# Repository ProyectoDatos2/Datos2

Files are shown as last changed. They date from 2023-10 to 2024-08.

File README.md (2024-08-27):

To change language:&nbsp;&nbsp;


# Datos² y EME

El proyecto [Datos²](https://datos2.redesclimaticas.com/) es una iniciativa de [OMIXOM](https://www.omixom.com/) En el se desarrolló un dispositivo Open-Source con el fin de recolectar, almacenar y compartir datos ambientales de la mano de proyectos de ciencia ciudadana y de la comunidad en general

Para contribuir al desarrollo de dispositivos que tomen datos, OMIXOM ha diseñado [EME](/Manual%20de%20uso.pdf) (Estación Meteorológica de uso Educativo), una estación meteorológica de bajo costo y fácil ensamblaje, ideal para proyectos educativos de tecnología y medio ambiente. EME está equipada con un sistema de sensores, telemetría y autonomía que permite medir variables como lluvia, temperatura, humedad y radiación UV, subiendo estos datos a la plataforma de Datos² sin necesidad de una red eléctrica.

<br><p align="center">
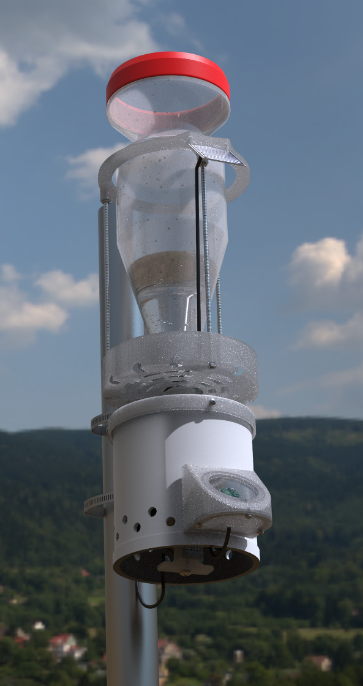
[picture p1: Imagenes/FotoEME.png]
  </p><br>

## Componentes y materiales
**Configuración de Impresión:**
- Altura de Capa: 0,2 mm
- Relleno: 30% al 50%
- Líneas de pared: 3
- Capas de Superficie: 3

<table align="center"><thead><tr>
      <th>Impresión 3D</th>
      <th>Cantidad</th></tr></thead><tbody><tr>
      <td align="center"><a href = "Impresion 3D STL\Pluviómetro\Pluv_Aro.STL">Aro</a></td>
      <td align="center">1</td></tr><tr>
      <td align="center"><a href = "Impresion 3D STL\Pluviómetro\Pluv_Estanco A.STL">Estanco A</a></td>
      <td align="center">1</td></tr><tr>
      <td align="center"><a href = "Impresion 3D STL\Pluviómetro\Pluv_Estanco B.STL">Estanco B</a></td>
      <td align="center">1</td></tr><tr>
      <td align="center"><a href = "Impresion 3D STL\Pluviómetro\Pluv_Localizador.STL">Localizador</a></td>
      <td align="center">1</td></tr><tr>
      <td align="center"><a href = "Impresion 3D STL\Pluviómetro\Pluv_Mensula.STL">Ménsula</a></td>
      <td align="center">1</td></tr><tr>
      <td align="center"><a href = "Impresion 3D STL\Pluviómetro\Pluv_Tapa.STL">Tapa pluviómetro</a></td>
      <td align="center">1</td></tr><tr>
      <td align="center"><a href = "Impresion 3D STL\Pluviómetro\Pluv_Totalizador.STL">Totalizador</a></td>
      <td align="center">1</td></tr><tr>
      <td align="center"><a href = "Impresion 3D STL\Telemetría\Tel_Holder Cargador.STL">Holder Cargador</a></td>
      <td align="center">1</td></tr><tr>
      <td align="center"><a href = "Impresion 3D STL\Telemetría\Tel_Holder Step Up.STL">Holder Step-Up</a></td>
      <td align="center">1</td></tr><tr>
      <td align="center"><a href = "Impresion 3D STL\Telemetría\Tel_Pieza T.STL">Pieza en T</a></td>
      <td align="center">1</td></tr><tr>
      <td align="center"><a href = "Impresion 3D STL\Telemetría\Tel_Placa Portapilas.STL">Placa Porta Pila</a></td>
      <td align="center">1</td></tr><tr>
      <td align="center"><a href = "Impresion 3D STL\Telemetría\Tel_Separador.STL">Separador</a></td>
      <td align="center">3</td></tr><tr>
      <td align="center"><a href = "Impresion 3D STL\Telemetría\Tel_Tapa Inferior.STL">Tapa Inferior</a></td>
      <td align="center">1</td></tr><tr>
      <td align="center"><a href = "Impresion 3D STL\Telemetría\Tel_Tapa Superior.STL">Tapa Superior</a></td>
      <td align="center">1</td></tr><tr>
      <td align="center"><a href = "Impresion 3D STL\Telemetría\Tel_Tope.STL">Topes</a></td>
      <td align="center">3</td></tr><tr>
      <td align="center"><a href = "Impresion 3D STL\UV\UV_Base.STL">Base</a></td>
      <td align="center">1</td></tr><tr>
      <td align="center"><a href = "Impresion 3D STL\UV\UV_Cuerpo.STL">Cuerpo</a></td>
      <td align="center">1</td></tr><tr>
      <td align="center"><a href = "Impresion 3D STL\UV\UV_Tapa.STL">Tapa UV</a></td>
      <td align="center">1</td></tr><tr>
      <td align="center"><a href = "Impresion 3D STL\Agarre\Agarre_Fijacion.STL">Fijación</a></td>
      <td align="center">2</td></tr><tr>
      <td align="center"><a href = "Impresion 3D STL\Agarre\Agarre_Mariposa.STL">Mariposa</a></td>
      <td align="center">4</td></tr></tbody></table>

<table align="left"><thead><tr>
      <th>Ferretería</th>
      <th>Cantidad</th></tr></thead><tbody><tr>
      <td align="center"><a href="https://articulo.mercadolibre.com.ar/MLA-935747094-pluviometro-plastico-luft-aro-medidor-lluvia-soporte-pared-_JM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">Pluviómetro</a></td>
      <td align="center">1 de Ø125 mm</td></tr><tr>
      <td align="center">Tornillos</td>
      <td align="center"><a href="https://articulo.mercadolibre.com.ar/MLA-1374684557-tornillos-para-electronica-phillips-fresada-m3-x-30mm-x-50u-_JM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">M3 x 8 mm x 8</a><br/><a href="https://articulo.mercadolibre.com.ar/MLA-851601087-tornillos-electronica-philips-m4-x-15mm-pack-x-50-unidades-_JM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">M4 x 15 mm x 4</a><br/><a href="https://www.google.com/search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">M4 x 75 mm x 3</a><br/><a href="https://articulo.mercadolibre.com.ar/MLA-1161252470-bulon-tornillo-motor-m6-x-45mm-exagono-8mm-tornado-shop-_JM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">M6 x 45 mm x 2</a></td></tr><tr>
      <td align="center">Tuercas</td>
      <td align="center"><a href="https://articulo.mercadolibre.com.ar/MLA-1530972980-tuerca-cuadrada-m4-llavelado-78mm-altura-3mm-x50u-_JM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">M3 x 2</a><br/><a href="https://articulo.mercadolibre.com.ar/MLA-852569160-tuercas-hexagonales-532-zincadas-x-100-unidades-_JM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">5/32" x 16</a><br/><a href="https://articulo.mercadolibre.com.ar/MLA-1754670680-tuerca-metrica-m6-x-1-por-100u-_JM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">M6 x 2</a></td></tr><tr>
      <td align="center"><a href="https://articulo.mercadolibre.com.ar/MLA-1620376638-arandela-plana-de-aluminio-532-m4-espesor-08mm-x50u-_JM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">Arandela</a></td>
      <td align="center">M4 x 4</td></tr><tr>
      <td align="center"><a href="https://articulo.mercadolibre.com.ar/MLA-856438789-varilla-roscada-zincada-metrica-4-mm-x-1-metro-5-unid-_JM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">Varilla Roscada</a></td>
      <td align="center">5/32" x 65 mm x 3</a><br/>5/32" x 210 mm x 3</td></tr><tr>
      <td align="center"><a href="https://articulo.mercadolibre.com.ar/MLA-1392845759-cable-plano-de-linea-telefono-4mts-rj11-4-hilos-_JM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">Cable de 4 Hilos</a></td>
      <td align="center">3 m</td></tr><tr>
      <td align="center"><a href="https://articulo.mercadolibre.com.ar/MLA-1110851260-prensacables-12-plasticopvcnylon-x10-unidades-_JM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">Prensacable Plástico 1/2</a></td>
      <td align="center">6</td></tr><tr>
      <td align="center"><a href="https://www.herrerocons.es/producto/manguito-union-tubo-pvc-110mm-claro-cod-1000717/">Tubo Unión PVC 110 mm</a></td>
      <td align="center">1</td></tr><tr>
      <td align="center"><a href="https://articulo.mercadolibre.com.ar/MLA-1137150523-junta-o-ring-goma-diametro-exterior-110mm-y-35mm-espesor-_JM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">O-Ring Ø110 mm</a></td>
      <td align="center">2</td></tr><tr>
      <td align="center"><a href="https://www.mercadolibre.com.ar/cristal-repuesto-lentes-para-soldar-truper/p/MLA26196668">Cristal de Soldadura</a></td>
      <td align="center">1</td></tr><tr>
      <td align="center"><a href="https://articulo.mercadolibre.com.ar/MLA-926213442-termocontraible-negro-6-mm-contrae-a-3-mm-por-1-metro-_JM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">Termocontraíble Ø3 mm</a></td>
      <td align="center">30 cm</td></tr><tr>
      <td align="center"><a href="https://www.mercadolibre.com.ar/sellador-tacsa-silicona-acetica-color-transparente/p/MLA27649062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">Silicona</a></td>
      <td align="center">Poco</td></tr><tr>
      <td align="center"><a href="https://www.mercadolibre.com.ar/ciano-pegamento-cianoacrilato-pegalo-x-20g/p/MLA27158011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">Pegamento Instantáneo</a></td>
      <td align="center">Poco</td></tr><tr>
      <td align="center"><a href="https://articulo.mercadolibre.com.ar/MLA-1320701568-acuarel-interior-y-exterior-latex-x-1-lt-_JM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">Pintura Látex</a></td>
      <td align="center">Poco</td></tr></tbody></table>

<table align="center"><thead><tr>
      <th>Componentes</th>
      <th>Cantidad</th></tr></thead><tbody><tr>
      <td align="center"><a href="https://www.trvstore.com/paneles-solares/113-mod-fotovoltaico-15-wp-18v-083a-16mm-tipo-szyl-p15-18c.html) y el [sensor de luz ultravioleta](https://articulo.mercadolibre.com.ar/MLA-921895103-modulo-sensor-luz-ultravioleta-uv-ml8511-arduino-_JM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">Panel Solar</a></td>
      <td align="center">1</td></tr><tr>
      <td align="center"><a href="https://articulo.mercadolibre.com.ar/MLA-1117390716-atmel-nano-v30-atmega328-usb-compatible-ch340-cable-usb-_JM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">Arduino Nano</a></td>
      <td align="center">1</td></tr><tr>
      <td align="center"><a href="https://articulo.mercadolibre.com.ar/MLA-677999119-fuente-step-up-mt3608-dc-dc-booster-hasta-28v-arduino-_JM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">Step-Up MT3608</a></td>
      <td align="center">1</td></tr><tr>
      <td align="center"><a href="https://articulo.mercadolibre.com.ar/MLA-732240129-modulo-driver-mosfet-irf520-24v-9a-controlador-arduino-pic-_JM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">Driver Mosfet IRF520</a></td>
      <td align="center">1</td></tr><tr>
      <td align="center"><a href="https://articulo.mercadolibre.com.ar/MLA-628919809-sensor-de-lluvia-raindrop-nivel-de-agua-gotas-arduino-pic-_JM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">Sensor de Lluvia</a></td>
      <td align="center">1</td></tr><tr>
      <td align="center"><a href="https://articulo.mercadolibre.com.ar/MLA-652467602-reloj-tiempo-real-rtc-ds1307-eeprom-24c32-arduino-todom">RTC DS1307</a></td>
      <td align="center">1</td></tr><tr>
      <td align="center"><a href="https://www.mercadolibre.com.ar/pila-samsung-inr18650-30q-cilindrica-1-unidad/p/MLA16952001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">Baterías 18650 Samsung</a></td>
      <td align="center">2</td></tr><tr>
      <td align="center"><a href="https://articulo.mercadolibre.com.ar/MLA-810911247-10-portapilas-holder-bateria-18650-portapila-pack-x-10-_JM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">Porta Baterías</a></td>
      <td align="center">2</td></tr><tr>
      <td align="center"><a href="https://articulo.mercadolibre.com.ar/MLA-767685589-dht-22-sensor-humedad-y-temperatura-arduino-raspberry-_JM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">Sensor de Humedad y Temperatura DHT22</a></td>
      <td align="center">1</td></tr><tr>
      <td align="center"><a href="https://articulo.mercadolibre.com.ar/MLA-921895103-modulo-sensor-luz-ultravioleta-uv-ml8511-arduino-_JM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">Sensor de Luz Ultravioleta ML8511</a></td>
      <td align="center">1</td></tr><tr>
      <td align="center"><a href="https://articulo.mercadolibre.com.ar/MLA-1437846022-modulo-gprs-a6-mini-cuatribanda-sms-gsm-gprs-ideal-arduino-_JM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">Módem GPRS A6 Mini</a> | <a href="https://articulo.mercadolibre.com.ar/MLA-1308505021-modulo-celular-gsm-gprs-sim800l-sim800-domotica-arduino-ubot-_JM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">SIM800L</a></td>
      <td align="center">1</td></tr><tr>
      <td align="center"><a href="https://articulo.mercadolibre.com.ar/MLA-1829687360-cargador-bateria-lipo-uso-panel-solar-cn3791-elegir-_JM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">Cargador Solar CN3791</a></td>
      <td align="center">1</td></tr><tr>
      <td align="center"><a href="https://articulo.mercadolibre.com.ar/MLA-733004040-celda-de-carga-10kg-con-amplificador-hx711-arduino-candy-_JM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">Celda de carga 10Kg con driver HX711</a></td>
      <td align="center">1</td></tr><tr>
      <td align="center">Kit Molex</td>
      <td align="center"><a href="https://articulo.mercadolibre.com.ar/MLA-1530414156-kit-x-30u-2-pin-terminal-molex-hembra-macho-y-pines-htec-_JM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">2 pines x 1</a><br/><a href="https://articulo.mercadolibre.com.ar/MLA-1547547796-kit-x-30u-3-pin-terminal-molex-hembra-macho-y-pines-htec-_JM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">3 pines x 3</a><br/><a href="https://articulo.mercadolibre.com.ar/MLA-1544835568-kit-x-30u-4-pin-terminal-molex-hembra-macho-y-pines-htec-_JM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">4 pines x 1</a><br/><a href="https://articulo.mercadolibre.com.ar/MLA-1548402732-kit-x-30u-5-pin-terminal-molex-hembra-macho-y-pines-htec-_JM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">5 pines x 1</a></td></tr><tr>
      <td align="center"><a href="https://articulo.mercadolibre.com.ar/MLA-841986521-10-x-resistencias-10k-ohm-1-14w-metal-film-_JM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">Resistencias 10 KΩ</a></td>
      <td align="center">2</td></tr><tr>
      <td align="center"><a href="https://articulo.mercadolibre.com.ar/MLA-879655442-tira-de-40-pines-hembra-paso-254mm-recta-1-fila-_JM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">Tira de Pines Hembra</a></td>
      <td align="center">2</td></tr><tr>
      <td align="center"><a href="https://articulo.mercadolibre.com.ar/MLA-1457486094-llave-electronica-tecla-interruptora-redonda-alcides-2500-_JM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">Interruptor de Encendido/Apagado</a></td>
      <td align="center">1</td></tr><tr>
      <td align="center"><a href="https://tienda.ityt.com.ar/antenas-gsm-2g-3g-4g/8259-antena-modem-2g-3g-4g-lte-exterior-cable-5m-sma-itytarg.html">Antena 3G</a></td>
      <td align="center">1</td></tr><tr>
      <td align="center"><a href="https://articulo.mercadolibre.com.ar/MLA-740053599-cable-pigtail-ufl-ipx-a-sma-hembra-cable-antena-15-cm-_JM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">Adaptador Pigtail SMA a U.fl</a></td>
      <td align="center">1</td></tr><tr>
      <td align="center"><a href="https://articulo.mercadolibre.com.ar/MLA-840122267-5-x-pilas-boton-cr2032-vinnic-2032-san-martin-caseros-_JM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">Pila CR2032</a></td>
      <td align="center">1</td></tr><tr>
      <td align="center"><a href="https://articulo.mercadolibre.com.ar/MLA-1248406422-chip-prepago-movistar-personal-claro-tuenti-gsm-4g-_JM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">Chip</a></td>
      <td align="center">1</td></tr></tbody></table><br>

## Armado de PCB

1. [Hacer el PCB](https://youtu.be/MX9_9U6Wnu8?si=8ijrH3XqB462RJCx&t=36) con este [circuito](EME/Arduino_Nano+A6mini_GPRS/Hardware/PCB_Datos2.pdf).

2. Perforar el PCB con mecha de 1 mm, así:
<p align="center">
  
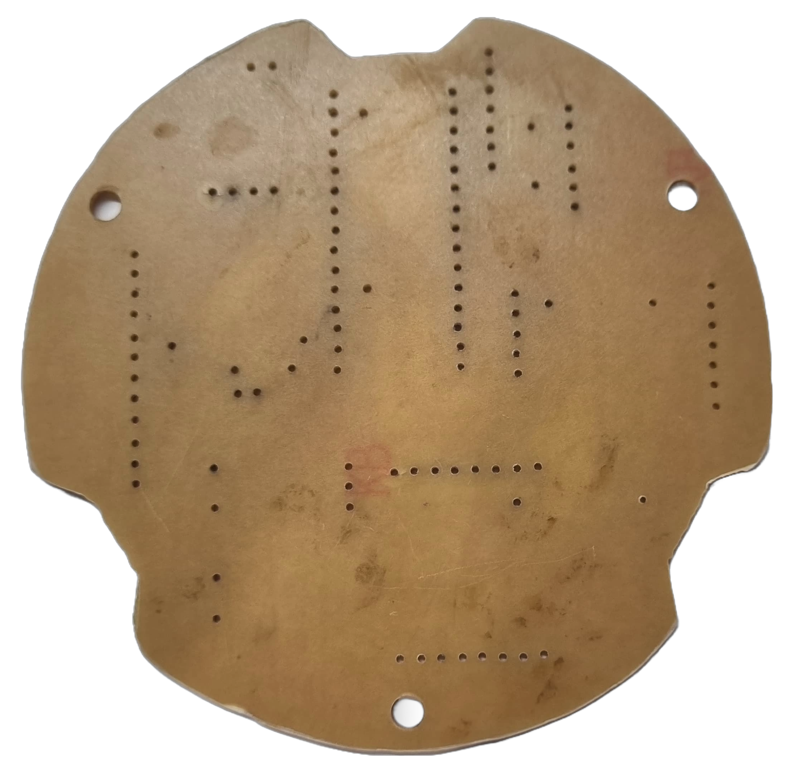
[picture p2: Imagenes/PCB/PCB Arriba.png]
  </p>

3. Comprobar que haya continuidad donde tiene que haber y que no haya donde no tiene que haber.

4. Soldar pines hembra, resistencias y cables así:
<p align="center">
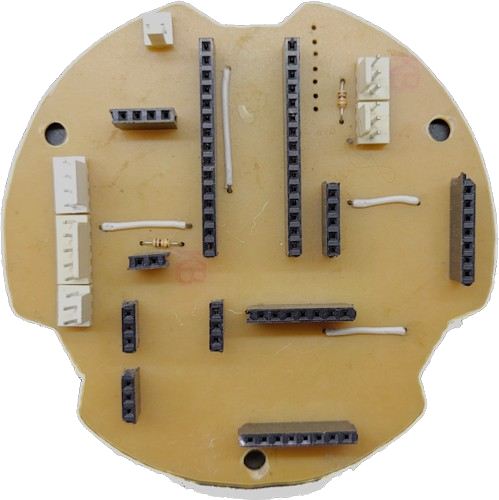
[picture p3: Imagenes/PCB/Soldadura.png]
  </p>

5. Enviar un correo electrónico a soporte@omixom.com para conseguir su número de serie.

6. [Instalar](https://docs.arduino.cc/software/ide-v1/tutorials/installing-libraries/) las [librerías](EME/Arduino_Nano+A6mini_GPRS/Firmware/Estacion_v1.4_1hora/Librerias/) y [cargar](https://docs.arduino.cc/software/ide-v2/tutorials/getting-started/ide-v2-uploading-a-sketch/) el [programa](EME/Arduino_Nano+A6mini_GPRS/Firmware/Estacion_v1.4_1hora/Estacion_v1.4_1hora.ino) (modificar la línea 30 con su número de serie) en el [Arduino](https://articulo.mercadolibre.com.ar/MLA-1117390716-atmel-nano-v30-atmega328-usb-compatible-ch340-cable-usb-_JM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).

7. Colocar el [Arduino](https://articulo.mercadolibre.com.ar/MLA-1117390716-atmel-nano-v30-atmega328-usb-compatible-ch340-cable-usb-_JM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), el [sensor de lluvia](https://articulo.mercadolibre.com.ar/MLA-628919809-sensor-de-lluvia-raindrop-nivel-de-agua-gotas-arduino-pic-_JM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), el [driver MOSFET](https://articulo.mercadolibre.com.ar/MLA-732240129-modulo-driver-mosfet-irf520-24v-9a-controlador-arduino-pic-_JM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), el [módem](https://articulo.mercadolibre.com.ar/MLA-1437846022-modulo-gprs-a6-mini-cuatribanda-sms-gsm-gprs-ideal-arduino-_JM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) (ponerle [adaptador pigtail](https://articulo.mercadolibre.com.ar/MLA-740053599-cable-pigtail-ufl-ipx-a-sma-hembra-cable-antena-15-cm-_JM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) y [chip](https://articulo.mercadolibre.com.ar/MLA-1248406422-chip-prepago-movistar-personal-claro-tuenti-gsm-4g-_JM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)) y el [RTC](https://articulo.mercadolibre.com.ar/MLA-652467602-reloj-tiempo-real-rtc-ds1307-eeprom-24c32-arduino-todom) (ponerle la [pila](https://articulo.mercadolibre.com.ar/MLA-840122267-5-x-pilas-boton-cr2032-vinnic-2032-san-martin-caseros-_JM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)).
<p align="center">
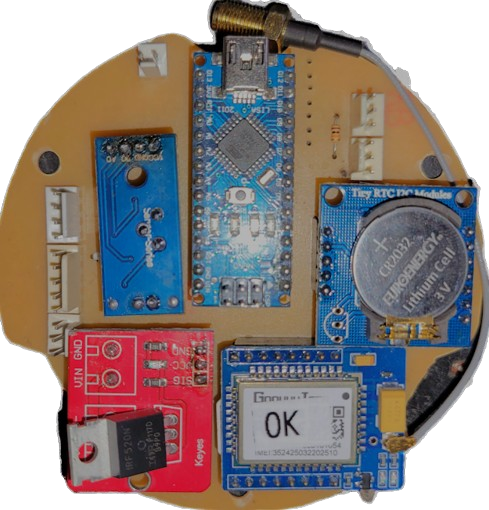
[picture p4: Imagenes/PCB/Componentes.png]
  </p><br>

## Sistema de Autonomía

1. Regular el [Step-Up](https://articulo.mercadolibre.com.ar/MLA-677999119-fuente-step-up-mt3608-dc-dc-booster-hasta-28v-desarrollo-_JM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) a 5V.

2. Pegar con el pegamento instantáneo: el [cargador solar](https://articulo.mercadolibre.com.ar/MLA-1106257985-cargador-bateria-lipo-uso-panel-solar-cn3791-arduino-elegir-_JM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) a [su holder](/Impresion%203D%20STL/Telemetría/Tel_Holder%20Cargador.STL), el [Step-Up](https://articulo.mercadolibre.com.ar/MLA-677999119-fuente-step-up-mt3608-dc-dc-booster-hasta-28v-desarrollo-_JM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) a [su holder](/Impresion%203D%20STL/Telemetría/Tel_Holder%20Step%20Up.STL) y los [porta baterías](https://articulo.mercadolibre.com.ar/MLA-810911247-10-portapilas-holder-bateria-18650-portapila-pack-x-10-_JM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) y holders a la [placa porta batería](/Impresion%203D%20STL/Telemetría/Tel_Placa%20Portapilas.STL).
<p align="center">
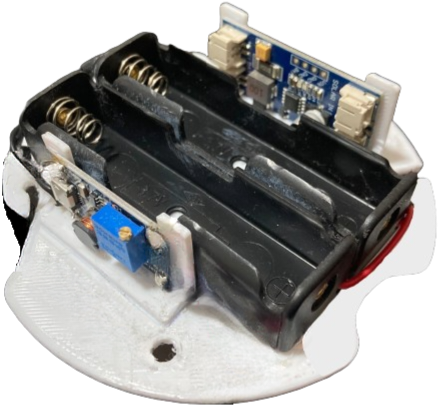
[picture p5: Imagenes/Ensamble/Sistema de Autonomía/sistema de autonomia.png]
  </p>

3. Colocar un [cable molex de 2 pines](https://www.google.com/search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) a todas las entradas y salidas del cargador solar.
 
4. Empalmar la salida superior del cargador solar con los porta baterías.
<p align="center">
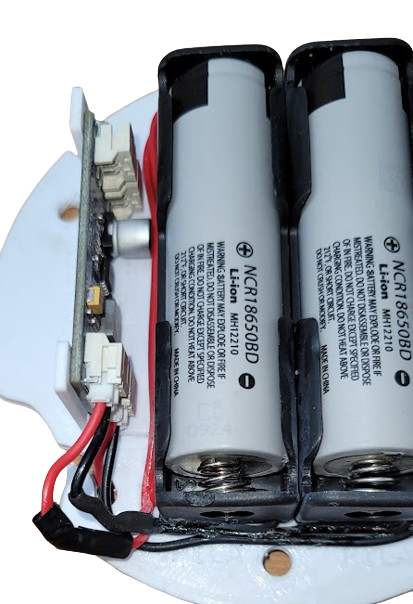
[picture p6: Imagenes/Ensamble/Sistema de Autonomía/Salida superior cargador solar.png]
  </p>
 
5. Conectar el negativo de la salida inferior del cargador solar con el negativo de la entrada del módulo Step-Up.
<p align="center">
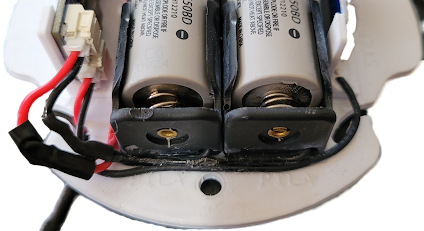
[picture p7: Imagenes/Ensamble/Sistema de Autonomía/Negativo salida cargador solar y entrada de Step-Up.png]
  </p>
 
6. Colocar un [cable de 4 hilos](https://articulo.mercadolibre.com.ar/MLA-1392845759-cable-plano-de-linea-telefono-4mts-rj11-4-hilos-_JM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) de 10cm en la salida del Step-Up, 2 hilos se conectan al positivo y los otros 2 al negativo.
<p align="center">
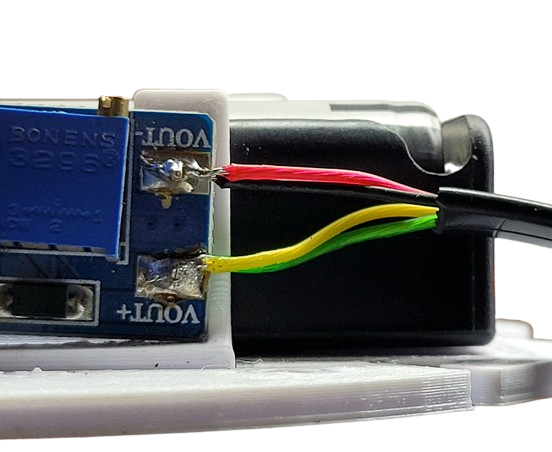
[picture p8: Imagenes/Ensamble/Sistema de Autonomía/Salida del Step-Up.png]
  </p><br>

## Sensor UV

1. Soldar un [cable de 4 hilos](https://articulo.mercadolibre.com.ar/MLA-1392845759-cable-plano-de-linea-telefono-4mts-rj11-4-hilos-_JM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) de 30cm al [sensor UV](https://articulo.mercadolibre.com.ar/MLA-921895103-modulo-sensor-luz-ultravioleta-uv-ml8511-arduino-_JM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) así:

<p align="center">
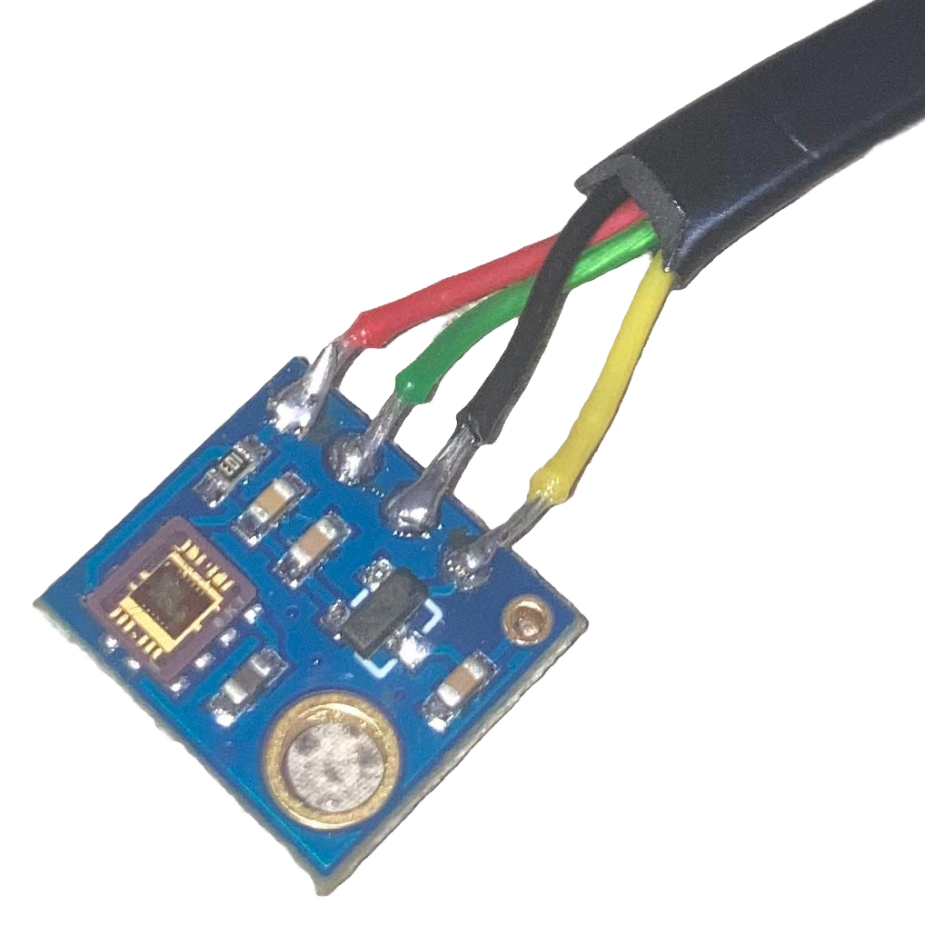
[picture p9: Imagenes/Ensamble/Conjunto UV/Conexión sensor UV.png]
  </p>

2. Atornillar el sensor a su [base](/Impresion%203D%20STL/UV/UV_Base.STL) (pasar el cable por el hueco) y la base al [cuerpo](/Impresion%203D%20STL/UV/UV_Cuerpo.STL) con [tornillos M3 de 8mm](https://articulo.mercadolibre.com.ar/MLA-1374684557-tornillos-para-electronica-phillips-fresada-m3-x-30mm-x-50u-_JM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). Pegar el [cristal](https://www.mercadolibre.com.ar/cristal-repuesto-lentes-para-soldar-truper/p/MLA26196668) al cuerpo con pegamento instantáneo y colocarle la [tapa UV](/Impresion%203D%20STL/UV/UV_Tapa.STL) encima.

<p align="center">
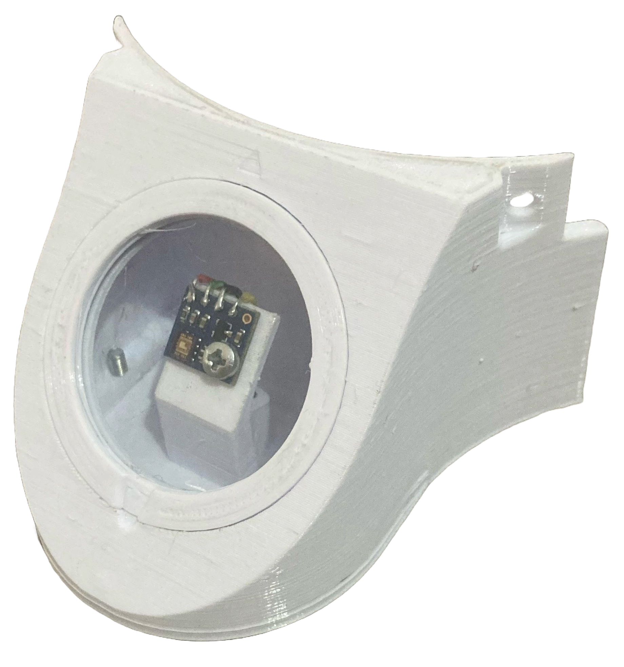
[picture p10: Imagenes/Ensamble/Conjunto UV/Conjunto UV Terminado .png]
  </p><br>

## Pluviómetro
1. Atornillar el [localizador](/Impresion%203D%20STL/Pluviómetro/Pluv_Localizador.STL) a la [celda de carga](https://articulo.mercadolibre.com.ar/MLA-733004040-celda-de-carga-10kg-con-amplificador-hx711-arduino-candy-_JM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) con doble arandela y [tornillos M4 de 15 mm](https://articulo.mercadolibre.com.ar/MLA-851601087-tornillos-electronica-philips-m4-x-15mm-pack-x-50-unidades-_JM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). Atornillar la celda de carga al [totalizador](/Impresion%203D%20STL/Pluviómetro/Pluv_Totalizador.STL) desde abajo con tornillo M4 de 15 mm.
<p align="center">
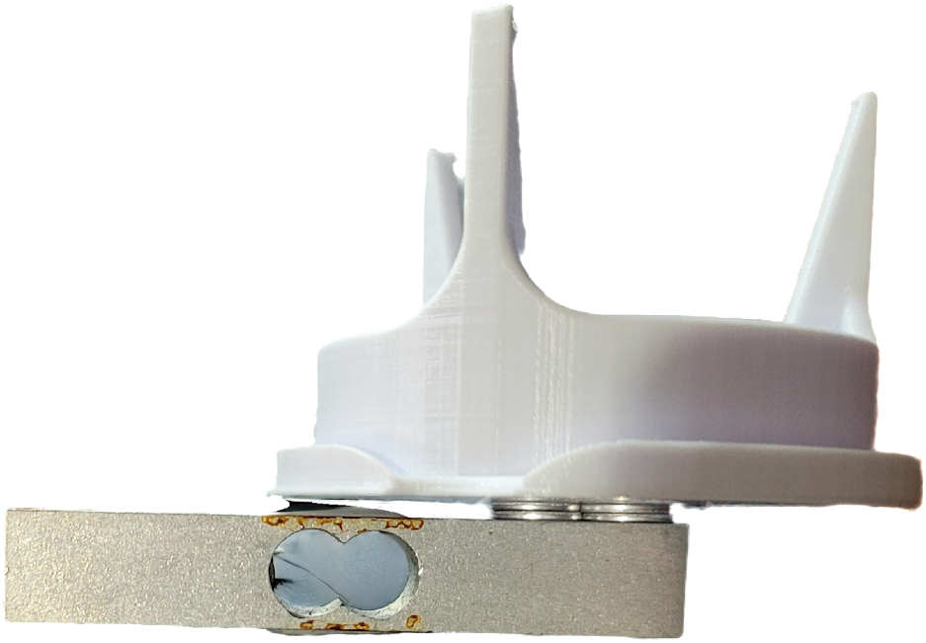
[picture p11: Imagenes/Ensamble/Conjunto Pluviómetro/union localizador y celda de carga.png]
  
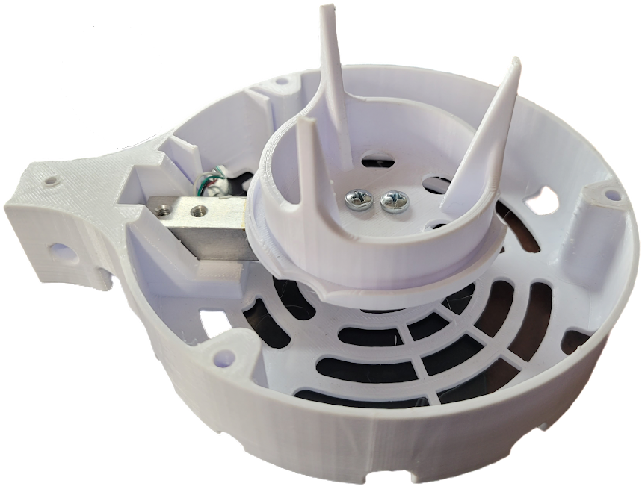
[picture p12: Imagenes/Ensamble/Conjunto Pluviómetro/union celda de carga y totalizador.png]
  </p>

2. Conectar la celda de carga y un [cable de 4 hilos](https://articulo.mercadolibre.com.ar/MLA-1392845759-cable-plano-de-linea-telefono-4mts-rj11-4-hilos-_JM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) de 40cm a su driver así:
<p align="center">
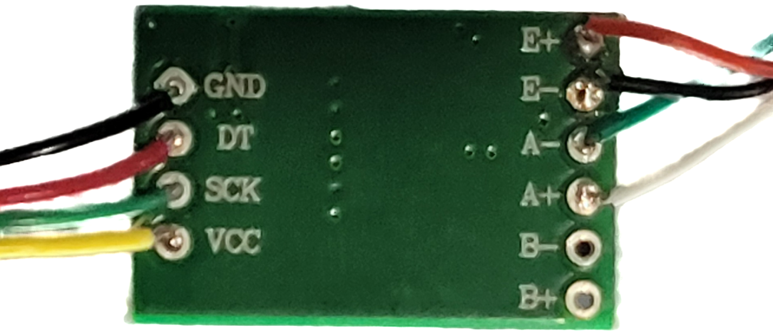
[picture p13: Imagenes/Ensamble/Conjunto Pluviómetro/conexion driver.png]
  </p>
  
3. Poner el driver adentro del [estanco A](/Impresion%203D%20STL/Pluviómetro/Pluv_Estanco%20A.STL), poner [silicona](https://www.mercadolibre.com.ar/sellador-tacsa-silicona-acetica-color-transparente/p/MLA27649062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), tapar con [estanco B](/Impresion%203D%20STL/Pluviómetro/Pluv_Estanco%20B.STL) y colocarlo al lado de la celda de carga.
<p align="center">
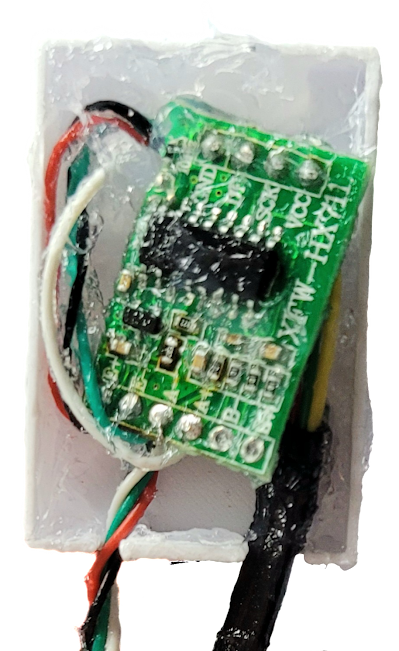
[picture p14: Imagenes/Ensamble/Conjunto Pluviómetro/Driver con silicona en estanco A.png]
  
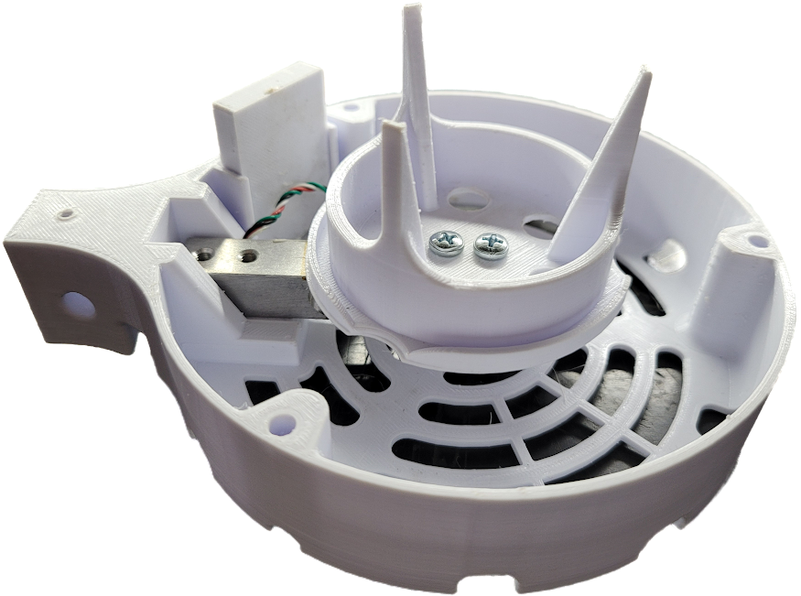
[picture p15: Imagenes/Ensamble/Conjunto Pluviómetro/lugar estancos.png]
  </p>
  
4. Colocar las [varillas](https://articulo.mercadolibre.com.ar/MLA-856438789-varilla-roscada-zincada-metrica-4-mm-x-1-metro-5-unid-_JM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) de 210 mm con [tuercas 5/32"](https://articulo.mercadolibre.com.ar/MLA-852569160-tuercas-hexagonales-532-zincadas-x-100-unidades-_JM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) en el totalizador, poner la [tapa pluviómetro](/Impresion%203D%20STL/Pluviómetro/Pluv_Tapa.STL) y tuercas 5/32".
<p align="center">
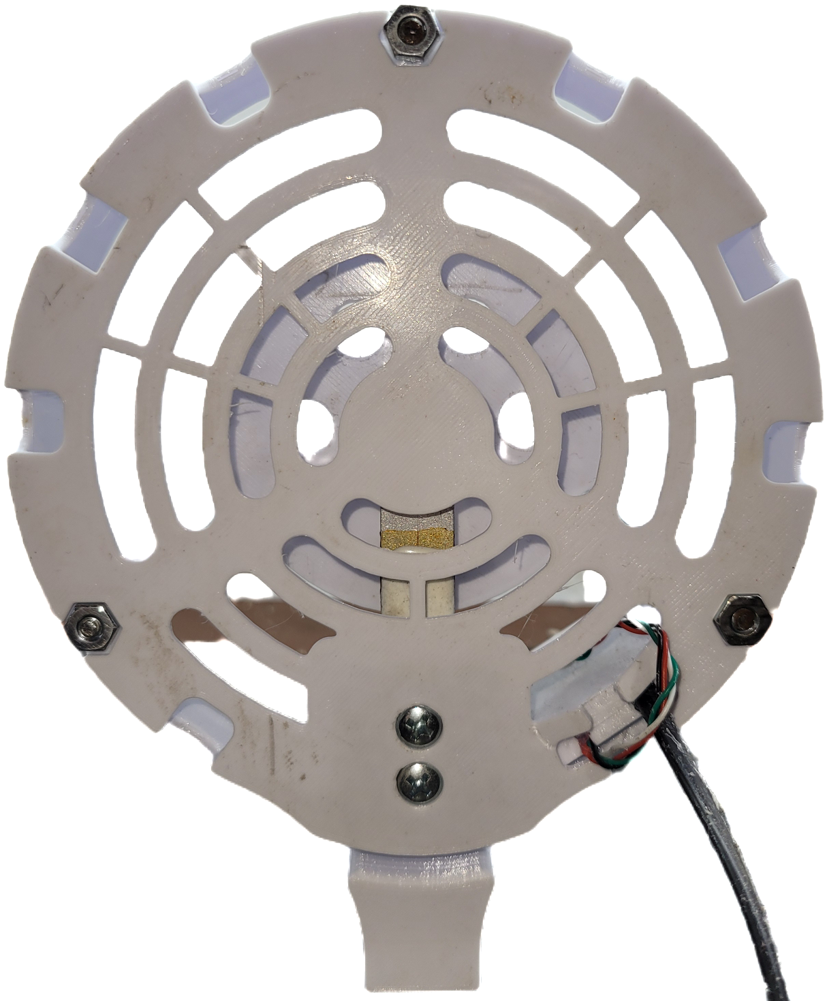
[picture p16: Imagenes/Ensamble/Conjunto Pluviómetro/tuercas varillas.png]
  
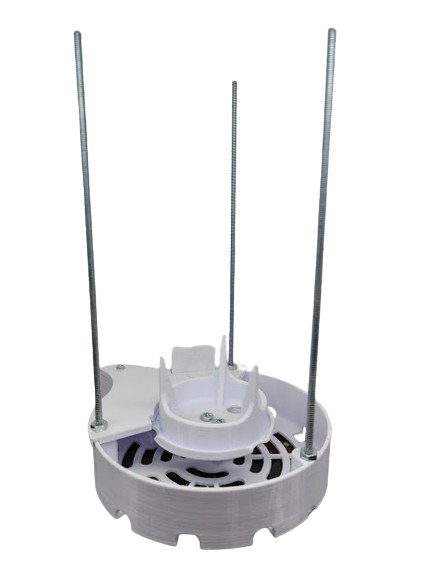
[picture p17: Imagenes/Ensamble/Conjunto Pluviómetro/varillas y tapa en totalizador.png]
  </p>
  
5. Pintar con [pintura látex](https://articulo.mercadolibre.com.ar/MLA-1320701568-acuarel-interior-y-exterior-latex-x-1-lt-_JM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) el [raindrop](https://articulo.mercadolibre.com.ar/MLA-628919809-sensor-de-lluvia-raindrop-nivel-de-agua-gotas-arduino-pic-_JM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), soldarle un cable de 4 hilos de 60 cm (2 hilos en un pad y 2 hilos en el otro) y atornillarlo en la [ménsula](/Impresion%203D%20STL/Pluviómetro/Pluv_Mensula.STL) con [tornillos M3 de 8 mm](https://articulo.mercadolibre.com.ar/MLA-1374684557-tornillos-para-electronica-phillips-fresada-m3-x-30mm-x-50u-_JM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).
<p align="center">
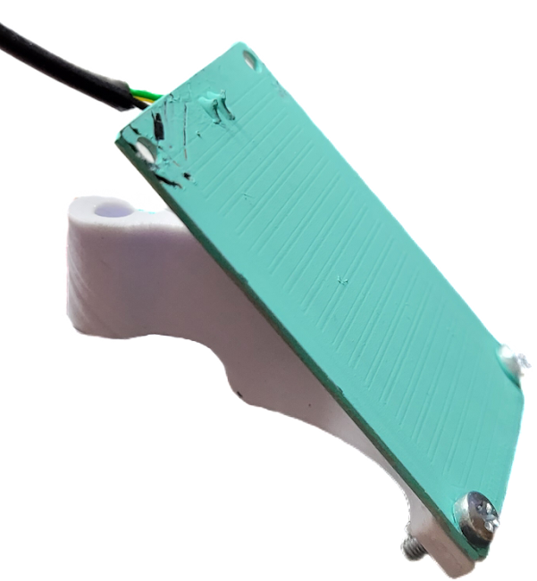
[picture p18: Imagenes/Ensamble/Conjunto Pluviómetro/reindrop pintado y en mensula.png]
  </p>
  
6. Colocar la ménsula y el [aro](/Impresion%203D%20STL/Pluviómetro/Pluv_Aro.STL) en las varillas. Nivelar el aro ajustando las tuercas.
<p align="center">
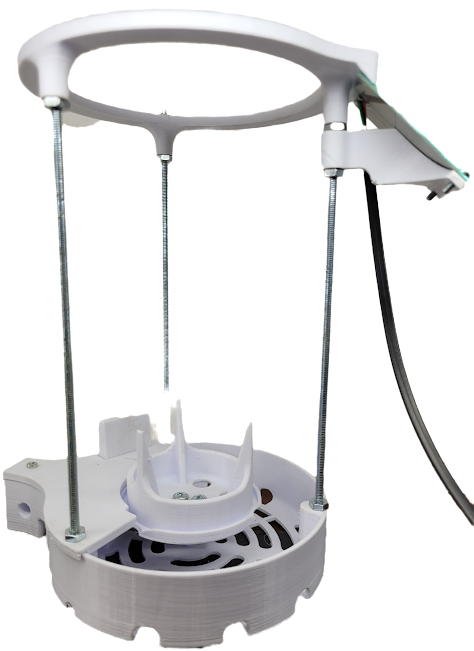
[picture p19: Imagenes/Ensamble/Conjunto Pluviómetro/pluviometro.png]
  
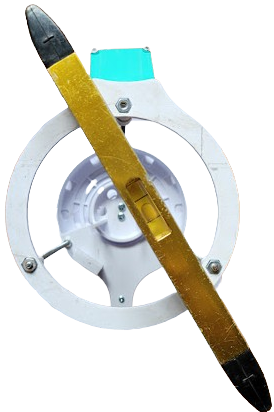
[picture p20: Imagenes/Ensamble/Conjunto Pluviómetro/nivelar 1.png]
  
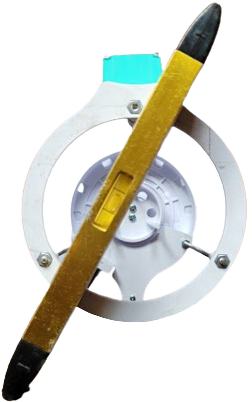
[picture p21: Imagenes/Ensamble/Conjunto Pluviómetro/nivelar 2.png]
  
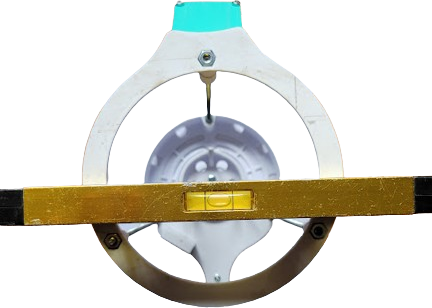
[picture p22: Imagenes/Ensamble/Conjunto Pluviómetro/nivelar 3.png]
  </p><br>

## Integración de los Sistemas Eléctricos

1. En la [tapa inferior](/Impresion%203D%20STL/Telemetría/Tel_Tapa%20Inferior.STL): colocar el [O-Ring](https://articulo.mercadolibre.com.ar/MLA-1137150523-junta-o-ring-goma-diametro-exterior-110mm-y-35mm-espesor-_JM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), enroscar las [varillas](https://articulo.mercadolibre.com.ar/MLA-856438789-varilla-roscada-zincada-metrica-4-mm-x-1-metro-5-unid-_JM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) de 65 mm, pegar con pegamento instantáneo la [pieza en T](/Impresion%203D%20STL/Telemetría/Tel_Pieza%20T.STL) e insertar los [prensacables](https://articulo.mercadolibre.com.ar/MLA-1110851260-prensacables-12-plasticopvcnylon-x10-unidades-_JM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) y el [interruptor](https://articulo.mercadolibre.com.ar/MLA-1457486094-llave-electronica-tecla-interruptora-redonda-alcides-2500-_JM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).

<p align="center">
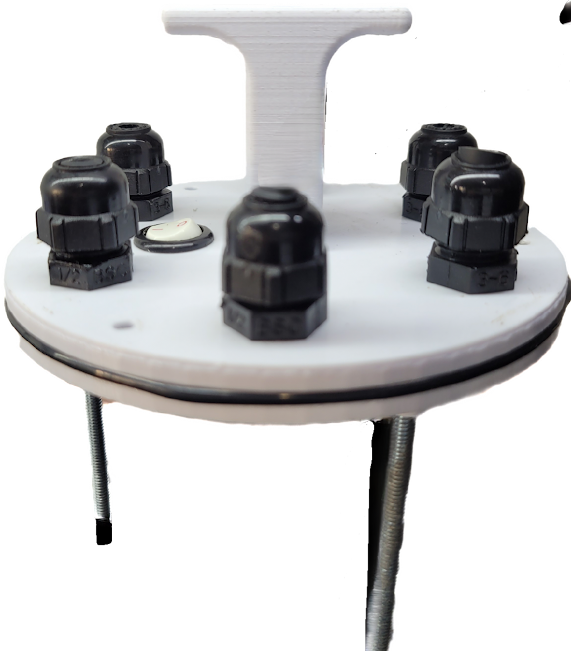
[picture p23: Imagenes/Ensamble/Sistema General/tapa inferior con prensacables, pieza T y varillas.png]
  </p>

2. Cortar a la mitad los pines del [DHT](https://articulo.mercadolibre.com.ar/MLA-767685589-dht-22-sensor-humedad-y-temperatura-arduino-raspberry-_JM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), soldar un cable de 4 polos de 20 cm a los pines utilizando termocontraíble y pegarlo con pegamento instantáneo a la pieza en T.

<p align="center">
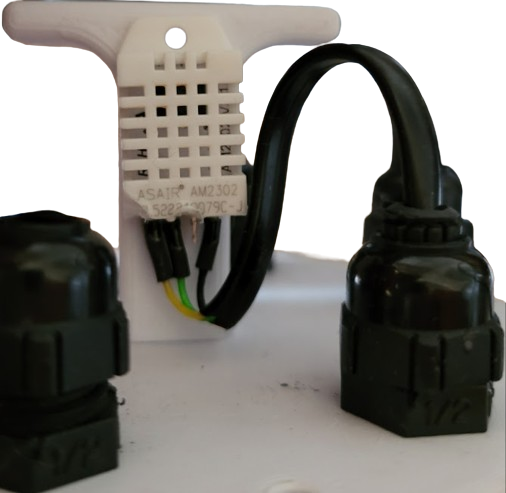
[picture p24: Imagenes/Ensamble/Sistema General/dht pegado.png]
  </p>

3. Del lado derecho del interruptor soldar un [cable de 4 hilos](https://articulo.mercadolibre.com.ar/MLA-1392845759-cable-plano-de-linea-telefono-4mts-rj11-4-hilos-_JM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) empalmados de 11 cm. Del lado izquierdo, soldar un cable de 4 hilos empalmados de 11 cm y un hilo de cable de 12 cm.

<p align="center">
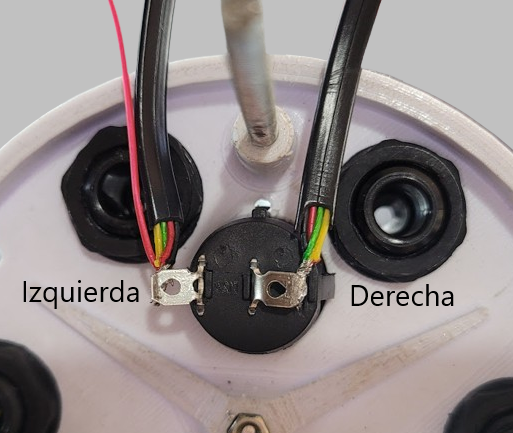
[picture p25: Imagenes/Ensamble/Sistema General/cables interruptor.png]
  </p>

4. Pasar los cables por los prensacables como en la imagen. Para que pase el [conector SMA de la antena](https://tienda.ityt.com.ar/antenas-gsm-2g-3g-4g/8259-antena-modem-2g-3g-4g-lte-exterior-cable-5m-sma-itytarg.html) hay que perforar el prensacable (sin la gomita) con una mecha de 9,5 mm. Dar 7 vueltas de cinta aislante donde va la gomita, pasar el conector SMA por el prensacable, conectarlo con el [SMA del pigtail](https://articulo.mercadolibre.com.ar/MLA-740053599-cable-pigtail-ufl-ipx-a-sma-hembra-cable-antena-15-cm-_JM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) del módem y darle unas vueltas de cinta aislante a la parte metálica.

<p align="center">
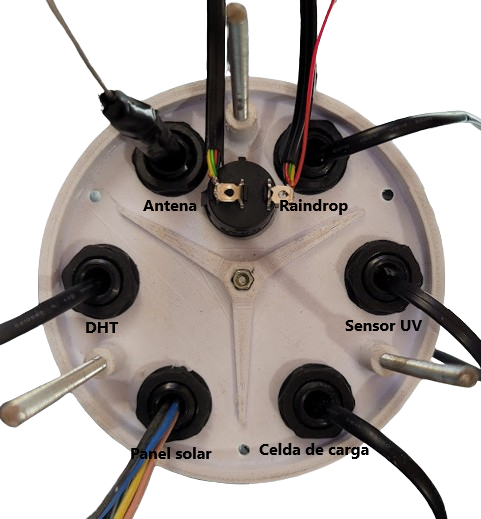
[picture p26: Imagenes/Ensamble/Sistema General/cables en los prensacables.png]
  
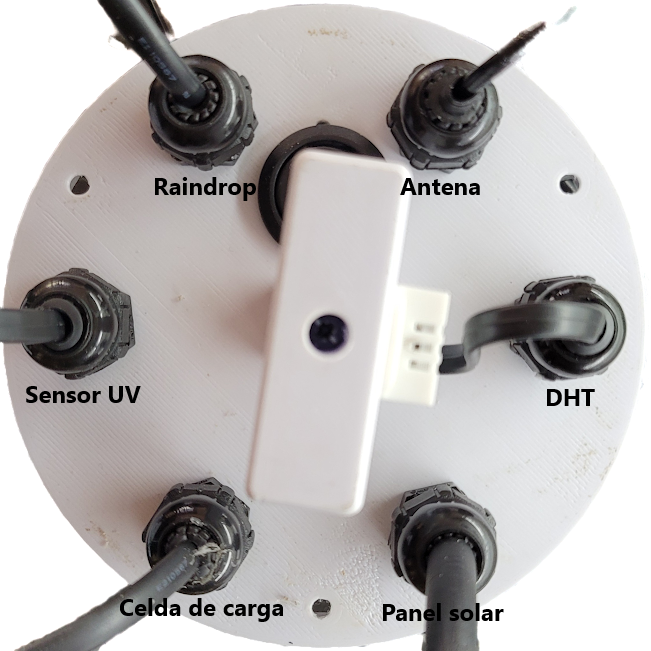
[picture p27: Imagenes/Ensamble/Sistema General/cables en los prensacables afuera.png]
  
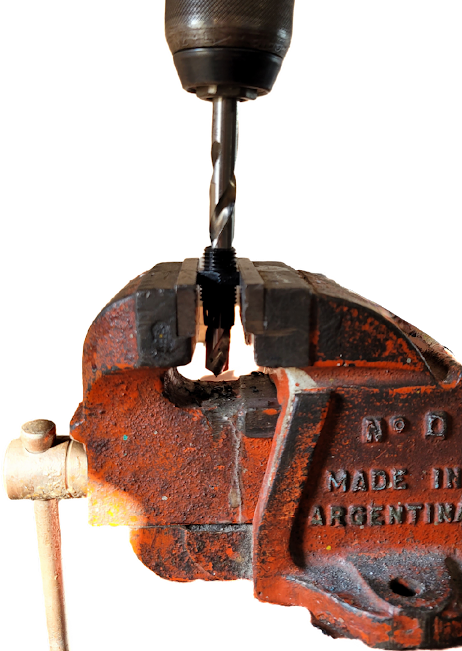
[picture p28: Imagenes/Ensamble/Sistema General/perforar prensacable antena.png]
  </p>

5. Colocar el PCB en las varillas de metal con la orientación de la imagen y armar los Molex así: 
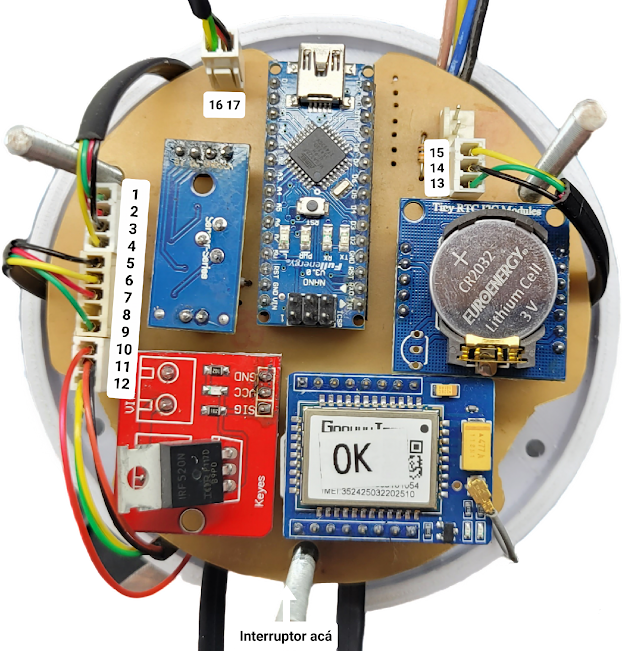
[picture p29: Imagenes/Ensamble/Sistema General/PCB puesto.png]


<table align="center"><thead><tr>
      <th>Molex</th>
      <th>Pin</th>
      <th>Uso</th></tr></thead><tbody><tr>
      <td align="center">Driver celda de carga</td>
      <td align="center">1<br>2<br>3<br>4</td>
      <td align="center">CLK<br>Datos<br>GND<br>VCC</td></tr><tr>
      <td align="center">Sensor Luz Ultravioleta</td>
      <td align="center">5<br>6<br>7<br>8<br>9</td>
      <td align="center">GND<br>3,3 V<br>ENABLE<br>NC<br>Datos</td></tr><tr>
      <td align="center">Interruptor + Raindrop</td>
      <td align="center">10<br>11<br>12</td>
      <td align="center">Voltaje Batería<br>Raindrop 1<br>Raindrop 2</td></tr><tr>
      <td align="center">Sensor Humedad y Temperatura</td>
      <td align="center">13<br>14<br>15</td>
      <td align="center">Datos<br>GND<br>VCC</td></tr><tr>
      <td align="center">Salida Step-Up</td>
      <td align="center">16<br>17</td>
      <td align="center">VCC<br>GND</td></tr></tbody></table>

6. Colocar los [separadores](/Impresion%203D%20STL/Telemetría/Tel_Separador.STL), el sistema de autonomía y [tuercas 5/32"](https://articulo.mercadolibre.com.ar/MLA-852569160-tuercas-hexagonales-532-zincadas-x-100-unidades-_JM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) en las varillas de metal.

<p align="center">
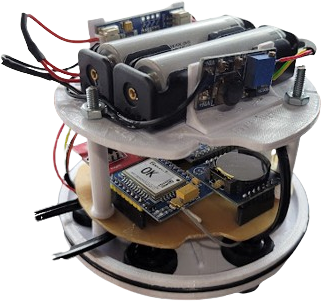
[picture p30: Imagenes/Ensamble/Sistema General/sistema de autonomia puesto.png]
  </p>

7. Empalmar el cable de 4 hilos de la derecha del interruptor en el positivo de la salida inferior del [cargador solar](https://articulo.mercadolibre.com.ar/MLA-1106257985-cargador-bateria-lipo-uso-panel-solar-cn3791-arduino-elegir-_JM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). Soldar el cable de 4 hilos de la izquierda del interruptor en el positivo de la entrada del [Step-Up](https://articulo.mercadolibre.com.ar/MLA-677999119-fuente-step-up-mt3608-dc-dc-booster-hasta-28v-arduino-_JM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).

<p align="center">
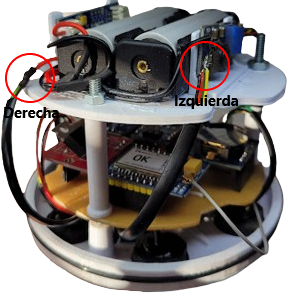
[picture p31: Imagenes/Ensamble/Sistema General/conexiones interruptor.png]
  </p><br>

8. Empalmar las entradas del cargador solar con el panel solar.  

<p align="center">
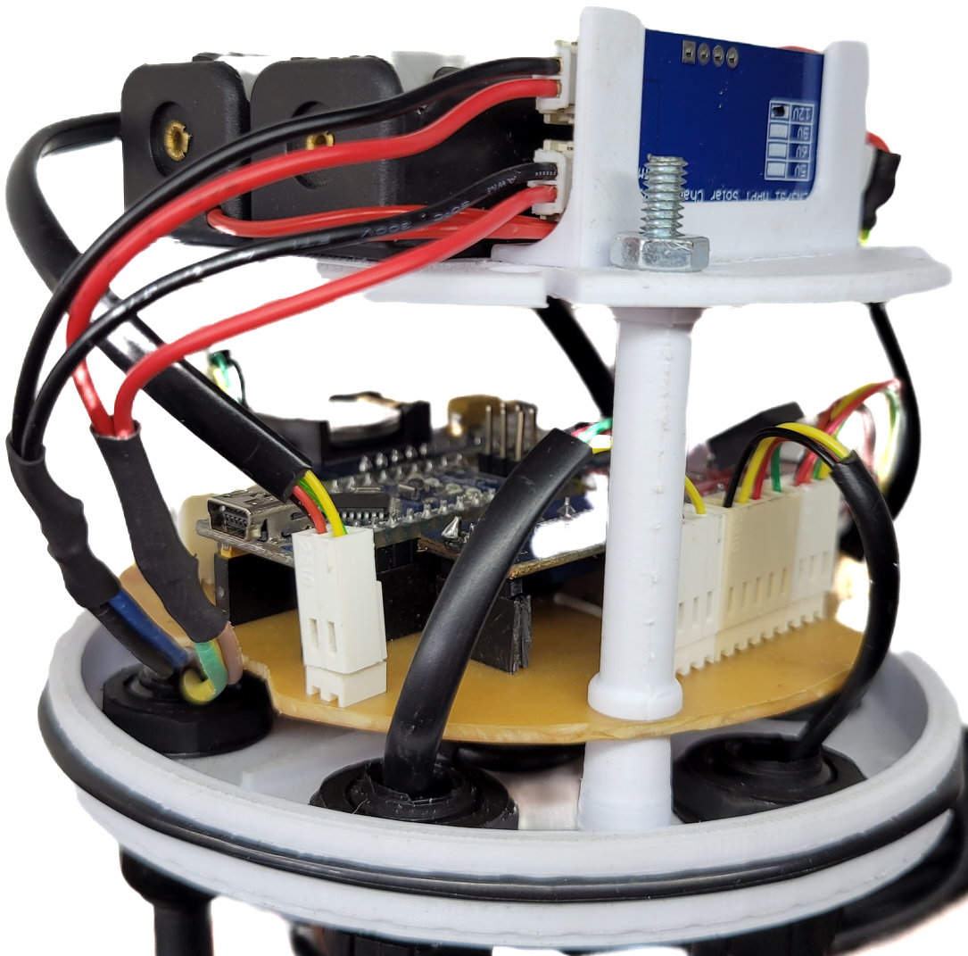
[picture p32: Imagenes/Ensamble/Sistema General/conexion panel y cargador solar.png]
  </p><br>

## Integración Total

1. Agujerear el [tubo](https://www.herrerocons.es/producto/manguito-union-tubo-pvc-110mm-claro-cod-1000717/) con huecos de 12 mm siguiendo esta [guía](/Impresion%203D%20STL/Guia%20de%20perforaciones%20para%20refugio.PDF).

<p align="center">
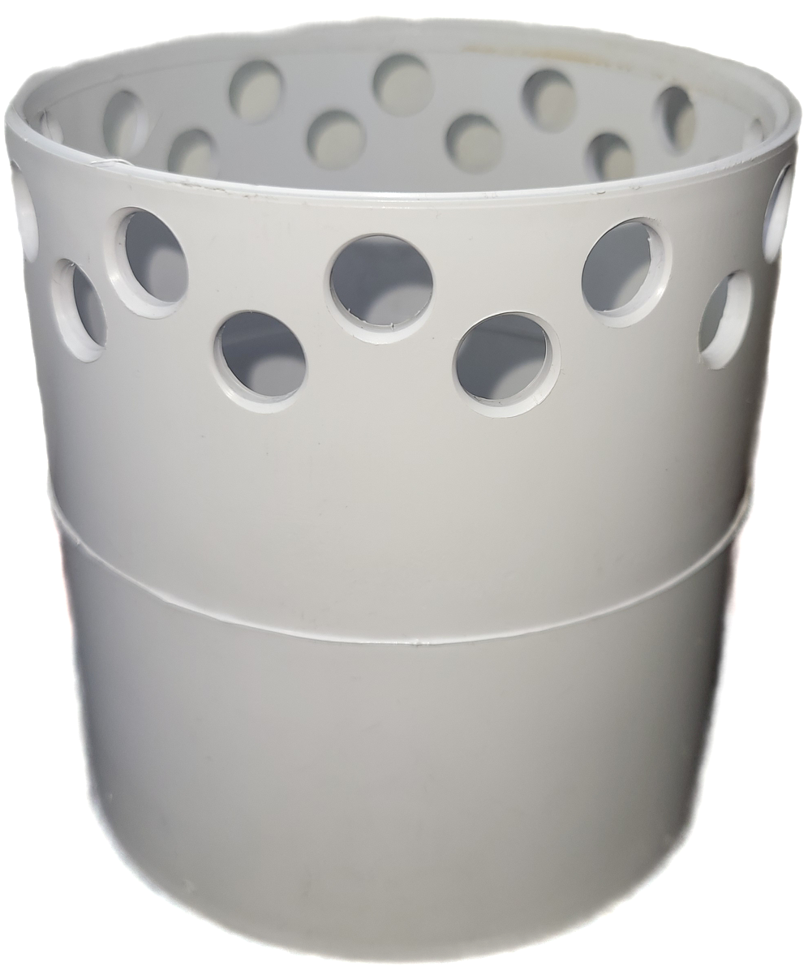
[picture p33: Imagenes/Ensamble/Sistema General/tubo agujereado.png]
  </p>

2. Colocar el [O-Ring](https://articulo.mercadolibre.com.ar/MLA-1137150523-junta-o-ring-goma-diametro-exterior-110mm-y-35mm-espesor-_JM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) y pegar los [topes](/Impresion%203D%20STL/Telemetría/Tel_Tope.STL) con pegamento instantáneo en la [tapa superior](/Impresion%203D%20STL/Telemetría/Tel_Tapa%20Superior.STL).

<p align="center">
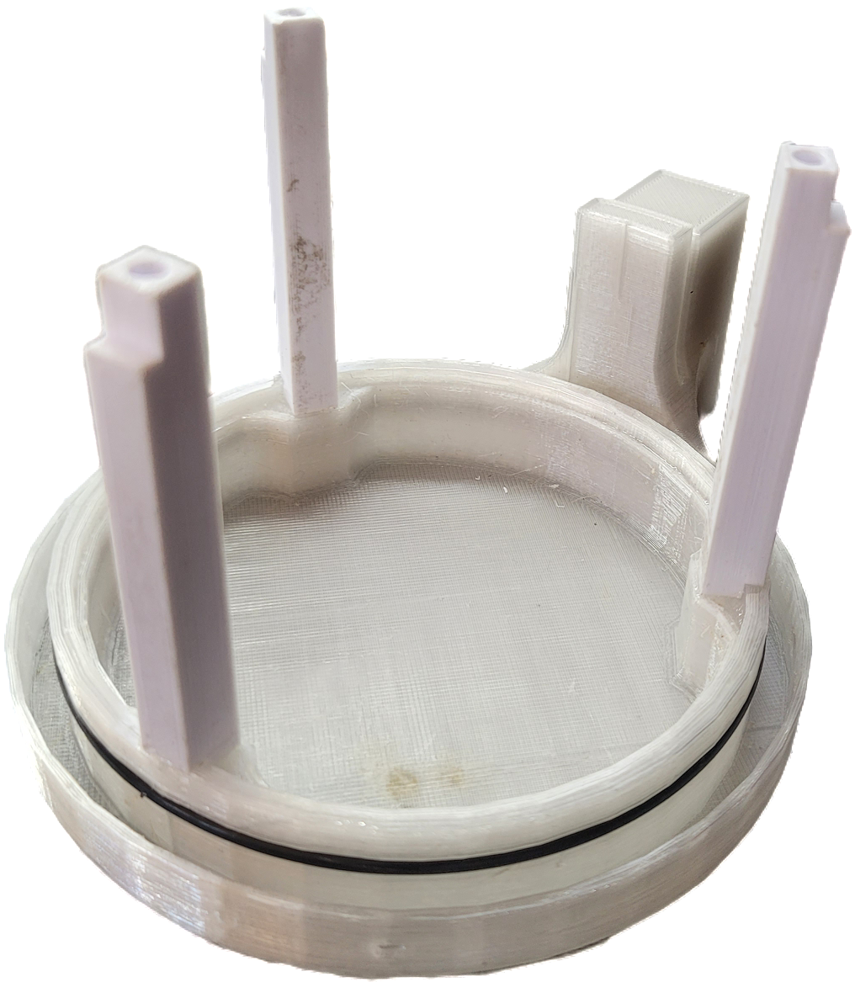
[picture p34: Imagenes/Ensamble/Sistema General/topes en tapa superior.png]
  </p>

3. Colocar el tubo en la tapa superior y atornillar la [base del sensor de luz ultravioleta](/Impresion%203D%20STL/UV/UV_Cuerpo.STL) con tornillos [M3 de 8 mm](https://articulo.mercadolibre.com.ar/MLA-1374684557-tornillos-para-electronica-phillips-fresada-m3-x-30mm-x-50u-_JM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) y [tuercas M3](https://articulo.mercadolibre.com.ar/MLA-1530972980-tuerca-cuadrada-m4-llavelado-78mm-altura-3mm-x50u-_JM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).

<p align="center">
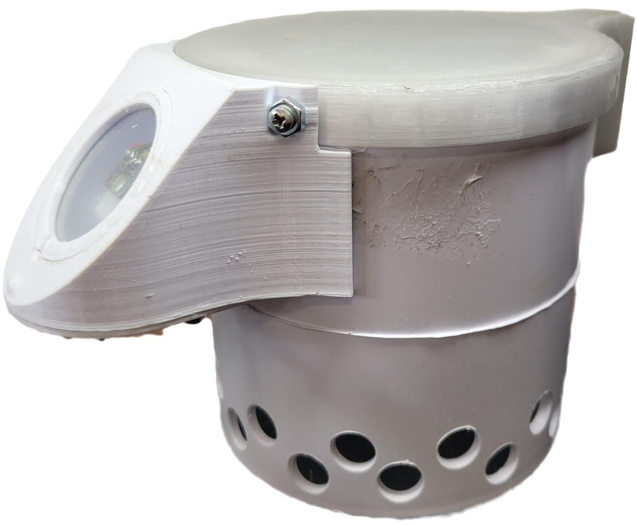
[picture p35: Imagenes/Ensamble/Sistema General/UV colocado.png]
  </p>

4. Insertar el sistema eléctrico en el tubo y atornillar los tornillos [M4 de 75 mm](https://www.google.com/search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) en los orificios de los topes.

<p align="center">
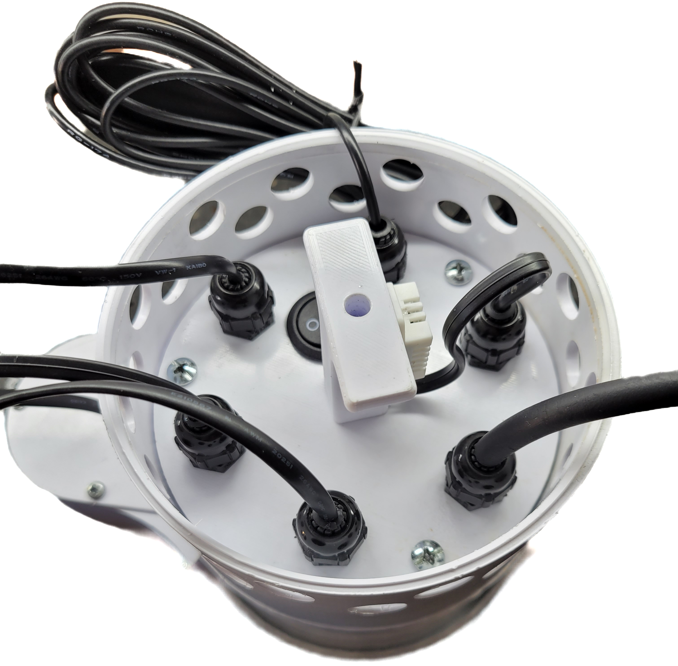
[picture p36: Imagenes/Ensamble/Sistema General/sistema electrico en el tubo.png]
  </p>

5. Colocar las [fijaciones](/Impresion%203D%20STL/Agarre/Agarre_Fijacion.STL) con un [tornillo](https://articulo.mercadolibre.com.ar/MLA-1161252470-bulon-tornillo-motor-m6-x-45mm-exagono-8mm-tornado-shop-_JM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) y [tuerca](https://articulo.mercadolibre.com.ar/MLA-1754670680-tuerca-metrica-m6-x-1-por-100u-_JM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) M6 de 45 mm y las [mariposas](/Impresion%203D%20STL/Agarre/Agarre_Mariposa.STL) en el agujero de la [tapa superior](/Impresion%203D%20STL/Telemetría/Tel_Tapa%20Superior.STL) y en el [totalizador](/Impresion%203D%20STL/Pluviómetro/Pluv_Totalizador.STL).
   
<p align="center">
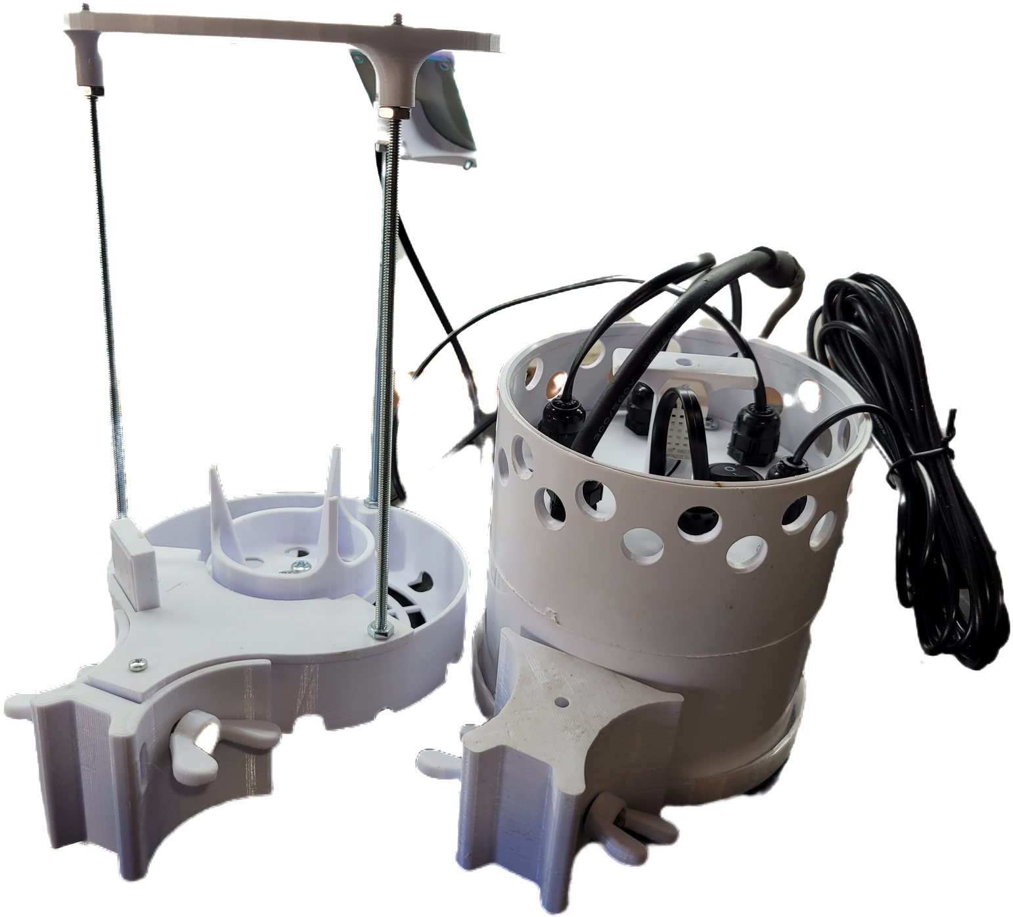
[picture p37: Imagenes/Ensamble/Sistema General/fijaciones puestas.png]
  </p>
   
La instalación tiene que ser en un lugar despejado, con el [panel solar](https://www.trvstore.com/paneles-solares/113-mod-fotovoltaico-15-wp-18v-083a-16mm-tipo-szyl-p15-18c.html) y el [sensor de luz ultravioleta](https://articulo.mercadolibre.com.ar/MLA-921895103-modulo-sensor-luz-ultravioleta-uv-ml8511-arduino-_JM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) apuntando al norte y el [pluviómetro](https://articulo.mercadolibre.com.ar/MLA-935747094-pluviometro-plastico-luft-aro-medidor-lluvia-soporte-pared-_JM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) puesto. Para facilitar esta instalación, las [fijaciones](/Impresion%203D%20STL/Agarre/Agarre_Fijacion.STL) tienen un agujero ovalado que se puede usar para sujetar el dispositivo, con precintos por ejemplo, a algún soporte.
Se recomienda leer el [manual de uso](/Manual%20de%20uso.pdf) para más información sobre el proyecto, el dispositivo y el cuidado y mantenimiento que hay que darle.

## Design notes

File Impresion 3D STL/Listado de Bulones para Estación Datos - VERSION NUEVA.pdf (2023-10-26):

Tipo de Bulón | Medidas | Equivalencia en | Cantidad (x estación) | Proveedor local | Nec. tuercas? | Localización
Phillips ò punta plana | M3 x 8mm | 1/8 x 1/4 | 14 | Bul.gral paz | | varios
Phillips ò punta plana Phillips ò punta plana Philips o punta plana | M3 x 30mm M4 x 16mm M4 x 75 | 1/8 x 1 1/4 5/32 x ½ 5/32 x 3 | 1 4 3 | Bul.gral paz Bul.gral paz Bul.gral paz | 1 | T de tapa inferio Celda de carga Tapa inferior
Varilla | M4 X210 | 5/32 x 210 | 3 | Bul.gral paz | 12 | Pluviómetro
Varilla | M4 X60 | 5/32 x 60 | 3 | Bul.gral paz | 3 | Telemetría int.
Tuerca Tuerca | M4 M3 | 5/32 1/8 | 16 1 | Bul.gral paz Bul.gral paz | | Varilla rosc.inter T de tapa inferio
Tornillo y Tuerca | M6 x 50 | ¼ x 2 | 2 | Bul. Gral paz | | Agarres
Elemento ferreteria | Medida | Cantidad | Proveedor local | | | Localización
Tubo Brida acero | 4" Para 4 pulgadas | 1 3 | | | | Cuerpo telemetría. 2 telemetria, 1 pluviometro
O´ring | W2,6 x D105 | 2 | | | | Tapas telemetría
Vidrio rep lente sold. | | 1 | | | | Sensor UV
Prensa cable Pluviómetro | | 5 1 | FILMS PILAS ESPECIALES | | | Tapa telemetría
STL | Peso (g) | Cantidad | Denominación CÓDIGO | Material | Tiempo impresión
Conjunto Telemetría Tapa superior | 87 | 1 | | PET/PLA
Tapa inferior | 29 | 1 | | PET/PLA
Topes | 6 | 3 | | PET/PLA
Base portapila Soporte Stepup | 22 2 | 1 1 | | PET/PLA PET/PLA
Soporte holder | 3 | 1 | | PET/PLA
Soporte telemetría | 37 | 1 | | PET/PLA
Pieza en T Separador pcb | 11 1 | 1 3 | | PET/PLA PET/PLA
Mariposa | 3 | 4 | | PET/PLA

Conjunto Pluviómetro

Aro totalizador | 31 | 1 | PET/PLA
Tapa estanco a Tapa estanco b Agarre caño Mensula sensor lluvia | 35 375 | 1111 | PET/PLA PET/PLA PET/PLA PET/PLA
localizador vaso | 22 | 1 | PET/PLA
Totalizador pluvióm. | 82 | 1 | PET/PLA
Tapa protectora viga | 12 | 1 | PET/PLA

Conjunto Sensor UV

Cuerpo principal | 43 | 1 | PET/PLA
Tapa inferior Protector de lente | 93 | 11 | PET/PLA PET/PLA
Cantidad de material | 476 | (60% relleno) | TP3D (CBA)

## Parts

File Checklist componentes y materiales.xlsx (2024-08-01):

Impresión 3D | Cantidad | Tengo | Ferretería | Cantidad | Tengo | Componentes | Cantidad | Tengo
Aro (https://github.com/ProyectoDatos2/Datos2/blob/mati-etche/Impresion%203D%20STL/Pluvi%C3%B3metro/Pluv_Aro.STL) | 1 | FALSE | Pluviómetro (https://articulo.mercadolibre.com.ar/MLA-935747094-pluviometro-plastico-luft-aro-medidor-lluvia-soporte-pared-_JM) | 1 de Ø125 mm | FALSE | Panel Solar (https://www.trvstore.com/paneles-solares/113-mod-fotovoltaico-15-wp-18v-083a-16mm-tipo-szyl-p15-18c.html)%20y%20el%20%5Bsensor%20de%20luz%20ultravioleta%5D(ht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) | 1 | FALSE
Estanco A (https://github.com/ProyectoDatos2/Datos2/blob/mati-etche/Impresion%203D%20STL/Pluvi%C3%B3metro/Pluv_Estanco%20A.STL) | 1 | FALSE | Tornillos | M3 x 8 mm x 8 M4 x 15 mm x 4 M4 x 75 mm x 3 M6 x 45 mm x 2 (https://articulo.mercadolibre.com.ar/MLA-1374684557-tornillos-para-electronica-phillips-fresada-m3-x-30mm-x-50u-_JM) | FALSE | Arduino Nano (https://articulo.mercadolibre.com.ar/MLA-1117390716-atmel-nano-v30-atmega328-usb-compatible-ch340-cable-usb-_JM) | 1 | FALSE
Estanco B (https://github.com/ProyectoDatos2/Datos2/blob/mati-etche/Impresion%203D%20STL/Pluvi%C3%B3metro/Pluv_Estanco%20B.STL) | 1 | FALSE |  |  | FALSE | Step-Up MT3608 (https://articulo.mercadolibre.com.ar/MLA-677999119-fuente-step-up-mt3608-dc-dc-booster-hasta-28v-arduino-_JM) | 1 | FALSE
Localizador (https://github.com/ProyectoDatos2/Datos2/blob/mati-etche/Impresion%203D%20STL/Pluvi%C3%B3metro/Pluv_Localizador.STL) | 1 | FALSE |  |  | FALSE | Driver Mosfet IRF520 (https://articulo.mercadolibre.com.ar/MLA-732240129-modulo-driver-mosfet-irf520-24v-9a-controlador-arduino-pic-_JM) | 1 | FALSE
Ménsula (https://github.com/ProyectoDatos2/Datos2/blob/mati-etche/Impresion%203D%20STL/Pluvi%C3%B3metro/Pluv_Mensula.STL) | 1 | FALSE |  |  | FALSE | Sensor de Lluvia (https://articulo.mercadolibre.com.ar/MLA-628919809-sensor-de-lluvia-raindrop-nivel-de-agua-gotas-arduino-pic-_JM) | 1 | FALSE
Tapa pluviómetro (https://github.com/ProyectoDatos2/Datos2/blob/mati-etche/Impresion%203D%20STL/Pluvi%C3%B3metro/Pluv_Tapa.STL) | 1 | FALSE | Tuercas | M3 x 2 5/32" x 16 M6 x 2 (https://articulo.mercadolibre.com.ar/MLA-1530972980-tuerca-cuadrada-m4-llavelado-78mm-altura-3mm-x50u-_JM) | FALSE | RTC DS1307 (https://articulo.mercadolibre.com.ar/MLA-652467602-reloj-tiempo-real-rtc-ds1307-eeprom-24c32-arduino-todom) | 1 | FALSE
Totalizador (https://github.com/ProyectoDatos2/Datos2/blob/mati-etche/Impresion%203D%20STL/Pluvi%C3%B3metro/Pluv_Totalizador.STL) | 1 | FALSE |  |  | FALSE | Baterías 18650 Samsung (https://www.mercadolibre.com.ar/pila-samsung-inr18650-30q-cilindrica-1-unidad/p/MLA16952001) | 2 | FALSE
Holder Cargador (https://github.com/ProyectoDatos2/Datos2/blob/mati-etche/Impresion%203D%20STL/Telemetr%C3%ADa/Tel_Holder%20Cargador.STL) | 1 | FALSE |  |  | FALSE | Porta Baterías (https://articulo.mercadolibre.com.ar/MLA-810911247-10-portapilas-holder-bateria-18650-portapila-pack-x-10-_JM) | 2 | FALSE
Holder Step-Up (https://github.com/ProyectoDatos2/Datos2/blob/mati-etche/Impresion%203D%20STL/Telemetr%C3%ADa/Tel_Holder%20Step%20Up.STL) | 1 | FALSE | Arandela (https://articulo.mercadolibre.com.ar/MLA-1620376638-arandela-plana-de-aluminio-532-m4-espesor-08mm-x50u-_JM) | M4 x 4 | FALSE | Sensor de Humedad y Temperatura DHT22 (https://articulo.mercadolibre.com.ar/MLA-767685589-dht-22-sensor-humedad-y-temperatura-arduino-raspberry-_JM) | 1 | FALSE
Pieza en T (https://github.com/ProyectoDatos2/Datos2/blob/mati-etche/Impresion%203D%20STL/Telemetr%C3%ADa/Tel_Pieza%20T.STL) | 1 | FALSE | Varilla Roscada (https://articulo.mercadolibre.com.ar/MLA-856438789-varilla-roscada-zincada-metrica-4-mm-x-1-metro-5-unid-_JM) | 5/32" x 65 mm x 3 5/32" x 210 mm x 3 | FALSE | Sensor de Luz Ultravioleta ML8511 (https://articulo.mercadolibre.com.ar/MLA-921895103-modulo-sensor-luz-ultravioleta-uv-ml8511-arduino-_JM) | 1 | FALSE
Placa Porta Pila (https://github.com/ProyectoDatos2/Datos2/blob/mati-etche/Impresion%203D%20STL/Telemetr%C3%ADa/Tel_Placa%20Portapilas.STL) | 1 | FALSE |  |  | FALSE | Módem GPRS A6 Mini | SIM800L (https://articulo.mercadolibre.com.ar/MLA-1437846022-modulo-gprs-a6-mini-cuatribanda-sms-gsm-gprs-ideal-arduino-_JM) | 1 | FALSE
Separador (https://github.com/ProyectoDatos2/Datos2/blob/mati-etche/Impresion%203D%20STL/Telemetr%C3%ADa/Tel_Separador.STL) | 3 | FALSE | Cable de 4 Hilos (https://articulo.mercadolibre.com.ar/MLA-1392845759-cable-plano-de-linea-telefono-4mts-rj11-4-hilos-_JM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) | 3 m | FALSE | Cargador Solar CN3791 (https://articulo.mercadolibre.com.ar/MLA-1106257985-cargador-bateria-lipo-uso-panel-solar-cn3791-arduino-elegir-_JM) | 1 | FALSE
Tapa Inferior (https://github.com/ProyectoDatos2/Datos2/blob/mati-etche/Impresion%203D%20STL/Telemetr%C3%ADa/Tel_Tapa%20Inferior.STL) | 1 | FALSE | Prensacable Plástico 1/2 (https://articulo.mercadolibre.com.ar/MLA-1110851260-prensacables-12-plasticopvcnylon-x10-unidades-_JM) | 6 | FALSE | Celda de carga 10Kg con driver HX711 (https://articulo.mercadolibre.com.ar/MLA-733004040-celda-de-carga-10kg-con-amplificador-hx711-arduino-candy-_JM) | 1 | FALSE
Tapa Superior (https://github.com/ProyectoDatos2/Datos2/blob/mati-etche/Impresion%203D%20STL/Telemetr%C3%ADa/Tel_Tapa%20Superior.STL) | 1 | FALSE | Tubo Unión PVC 110 mm (https://www.herrerocons.es/producto/manguito-union-tubo-pvc-110mm-claro-cod-1000717/) | 1 | FALSE | Kit Molex | 2 pines x 1 3 pines x 3 4 pines x 1 5 pines x 1 (https://articulo.mercadolibre.com.ar/MLA-1530414156-kit-x-30u-2-pin-terminal-molex-hembra-macho-y-pines-htec-_JM) | FALSE
Topes (https://github.com/ProyectoDatos2/Datos2/blob/mati-etche/Impresion%203D%20STL/Telemetr%C3%ADa/Tel_Tope.STL) | 3 | FALSE | O-Ring Ø110 mm (https://articulo.mercadolibre.com.ar/MLA-1137150523-junta-o-ring-goma-diametro-exterior-110mm-y-35mm-espesor-_JM) | 2 | FALSE |  |  | FALSE
Base (https://github.com/ProyectoDatos2/Datos2/blob/mati-etche/Impresion%203D%20STL/UV/UV_Base.STL) | 1 | FALSE | Cristal de Soldadura (https://www.mercadolibre.com.ar/cristal-repuesto-lentes-para-soldar-truper/p/MLA26196668) | 1 | FALSE |  |  | FALSE
Cuerpo (https://github.com/ProyectoDatos2/Datos2/blob/mati-etche/Impresion%203D%20STL/UV/UV_Cuerpo.STL) | 1 | FALSE | Termocontraíble Ø3 mm (https://articulo.mercadolibre.com.ar/MLA-926213442-termocontraible-negro-6-mm-contrae-a-3-mm-por-1-metro-_JM) | 30 cm | FALSE |  |  | FALSE
Tapa UV (https://github.com/ProyectoDatos2/Datos2/blob/mati-etche/Impresion%203D%20STL/UV/UV_Tapa.STL) | 1 | FALSE | Silicona (https://www.mercadolibre.com.ar/sellador-tacsa-silicona-acetica-color-transparente/p/MLA27649062) | Poco | FALSE | Resistencias 10 KΩ (https://articulo.mercadolibre.com.ar/MLA-841986521-10-x-resistencias-10k-ohm-1-14w-metal-film-_JM) | 2 | FALSE
Fijación (https://github.com/ProyectoDatos2/Datos2/blob/mati-etche/Impresion%203D%20STL/Agarre/Agarre_Fijacion.STL) | 2 | FALSE | Pegamento Instantáneo (https://www.mercadolibre.com.ar/ciano-pegamento-cianoacrilato-pegalo-x-20g/p/MLA27158011) | Poco | FALSE | Tira de Pines Hembra (https://articulo.mercadolibre.com.ar/MLA-879655442-tira-de-40-pines-hembra-paso-254mm-recta-1-fila-_JM) | 2 | FALSE
Mariposa (https://github.com/ProyectoDatos2/Datos2/blob/mati-etche/Impresion%203D%20STL/Agarre/Agarre_Mariposa.STL) | 4 | FALSE | Pintura Látex (https://articulo.mercadolibre.com.ar/MLA-1320701568-acuarel-interior-y-exterior-latex-x-1-lt-_JM?quantity=1) | Poco | FALSE | Interruptor de Encendido/Apagado (https://articulo.mercadolibre.com.ar/MLA-1457486094-llave-electronica-tecla-interruptora-redonda-alcides-2500-_JM) | 1 | FALSE
 |  |  |  |  |  | Antena 3G (https://tienda.ityt.com.ar/antenas-gsm-2g-3g-4g/8259-antena-modem-2g-3g-4g-lte-exterior-cable-5m-sma-itytarg.html) | 1 | FALSE
 |  |  |  |  |  | Adaptador Pigtail SMA a U.fl (https://articulo.mercadolibre.com.ar/MLA-740053599-cable-pigtail-ufl-ipx-a-sma-hembra-cable-antena-15-cm-_JM) | 1 | FALSE
 |  |  |  |  |  | Pila CR2032 (https://articulo.mercadolibre.com.ar/MLA-840122267-5-x-pilas-boton-cr2032-vinnic-2032-san-martin-caseros-_JM) | 1 | FALSE
 |  |  |  |  |  | Chip (https://articulo.mercadolibre.com.ar/MLA-1248406422-chip-prepago-movistar-personal-claro-tuenti-gsm-4g-_JM) | 1 | FALSE

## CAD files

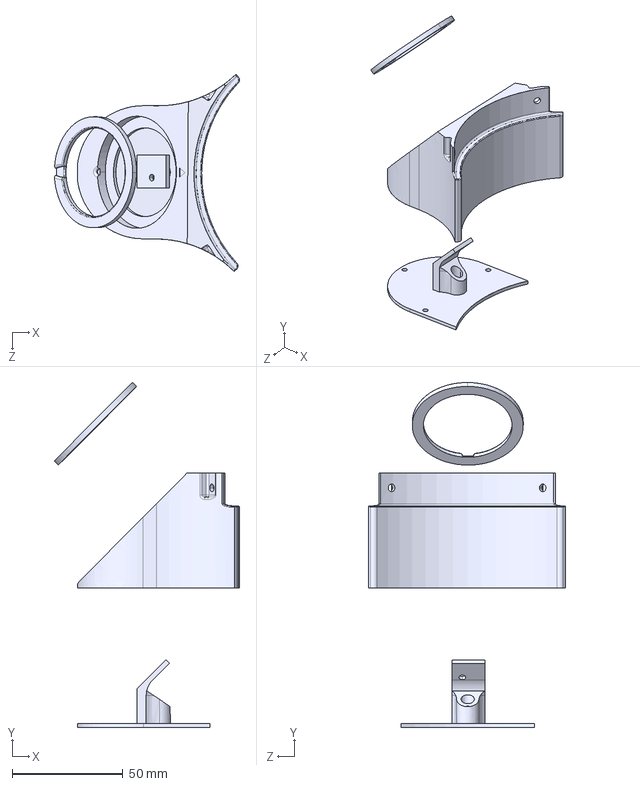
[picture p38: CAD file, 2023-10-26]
Piezas IGS/Conjunto sensor UV/Ensamblaje sensor UV.IGS
83.4 x 155.4 x 88.9 mm

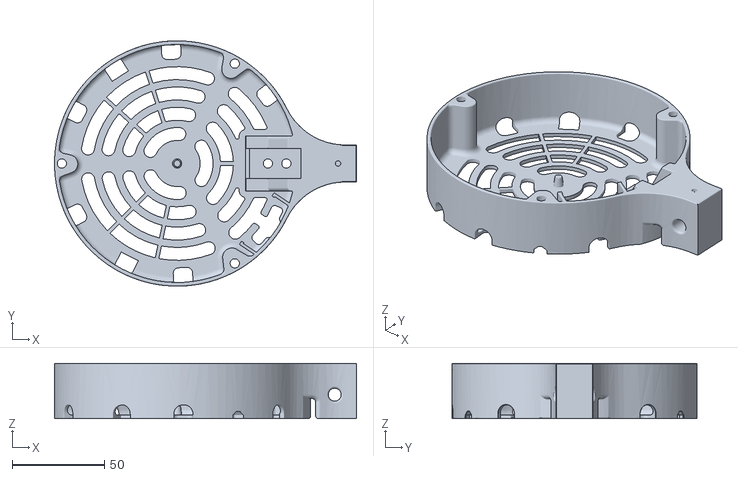
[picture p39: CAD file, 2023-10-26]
Impresion 3D STL/Pluviómetro/Pluv_Totalizador.STL
163.7 x 133.0 x 30.0

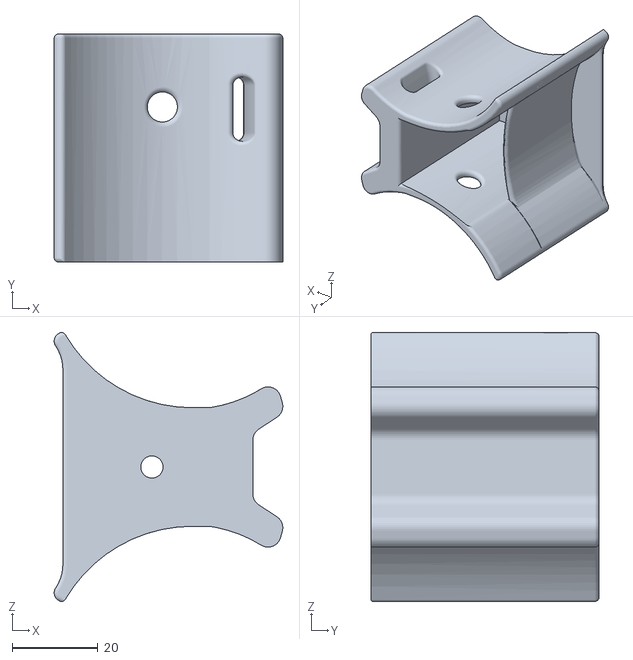
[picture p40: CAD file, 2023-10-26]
Impresion 3D STL/Agarre/Agarre_Fijacion.STL
53.2 x 53.1 x 62.6

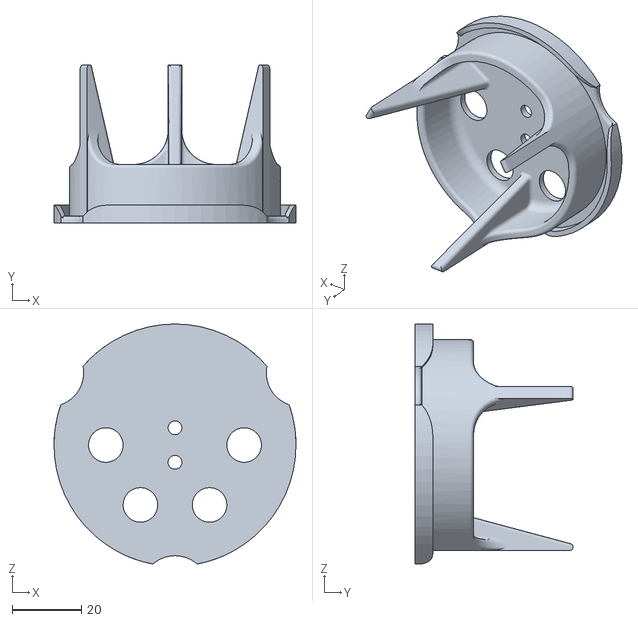
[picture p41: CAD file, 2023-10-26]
Impresion 3D STL/Pluviómetro/Pluv_Localizador.STL
70.0 x 45.8 x 69.4

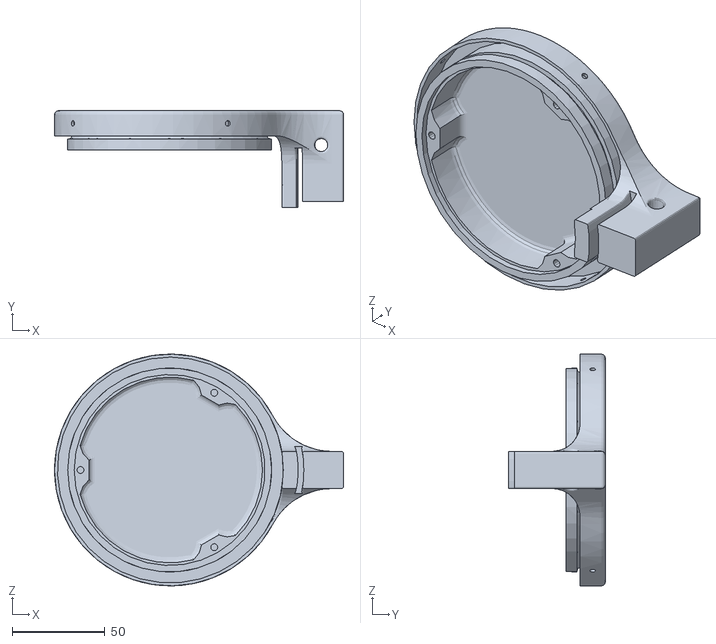
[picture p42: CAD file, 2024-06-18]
Impresion 3D STL/Telemetría/Tel_Tapa Superior.STL
155.6 x 52.0 x 124.8

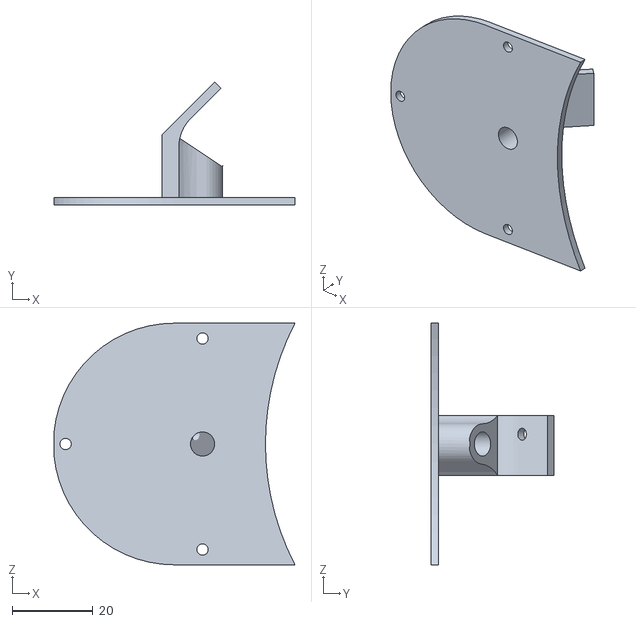
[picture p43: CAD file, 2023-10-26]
Impresion 3D STL/UV/UV_Base.STL
59.9 x 30.4 x 60.0

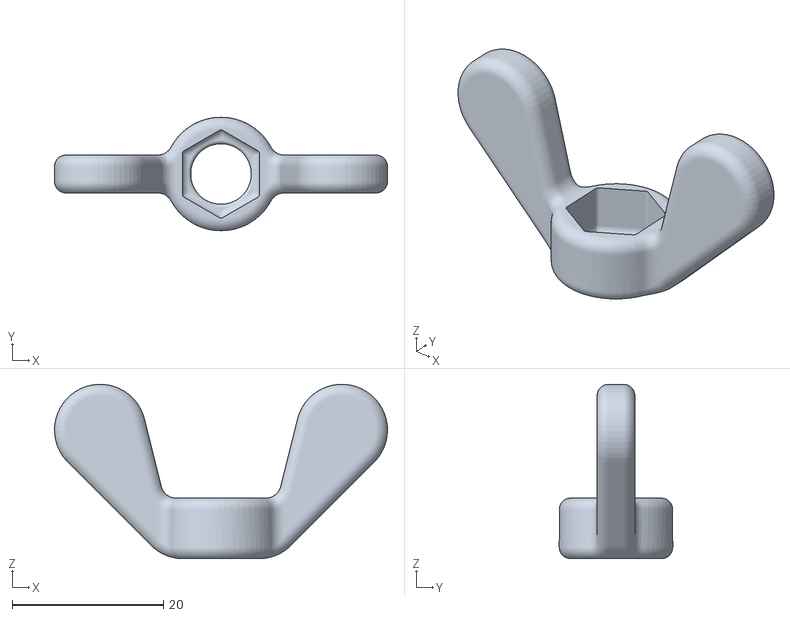
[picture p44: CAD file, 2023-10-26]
Impresion 3D STL/Agarre/Agarre_Mariposa.STL
44.0 x 15.0 x 23.0

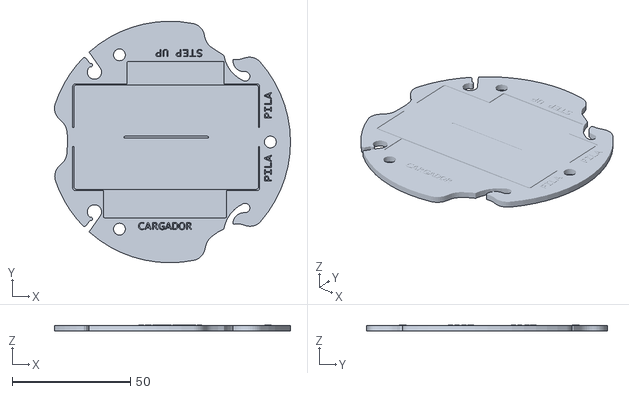
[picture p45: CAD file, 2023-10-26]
Impresion 3D STL/Telemetría/Tel_Placa Portapilas.STL
99.7 x 102.0 x 2.70

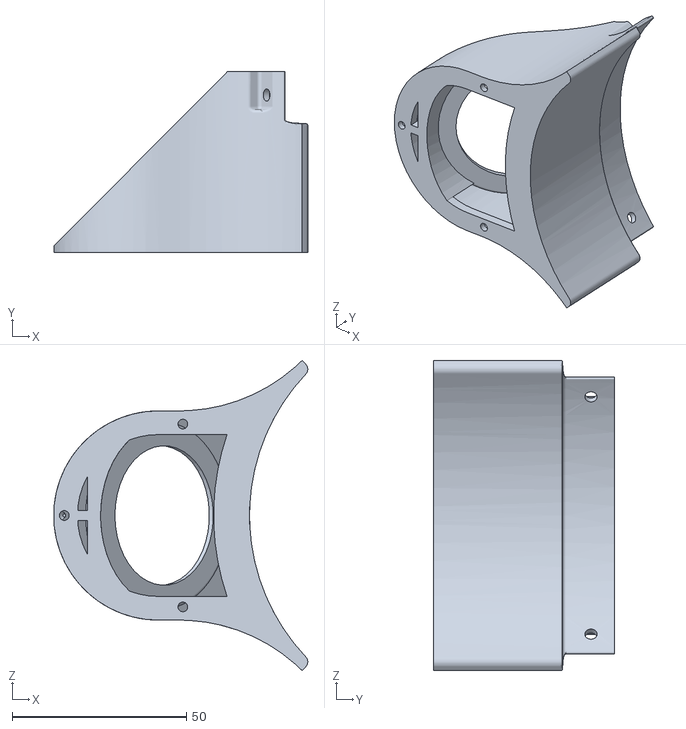
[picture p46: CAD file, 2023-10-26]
Impresion 3D STL/UV/UV_Cuerpo.STL
72.7 x 52.0 x 88.9

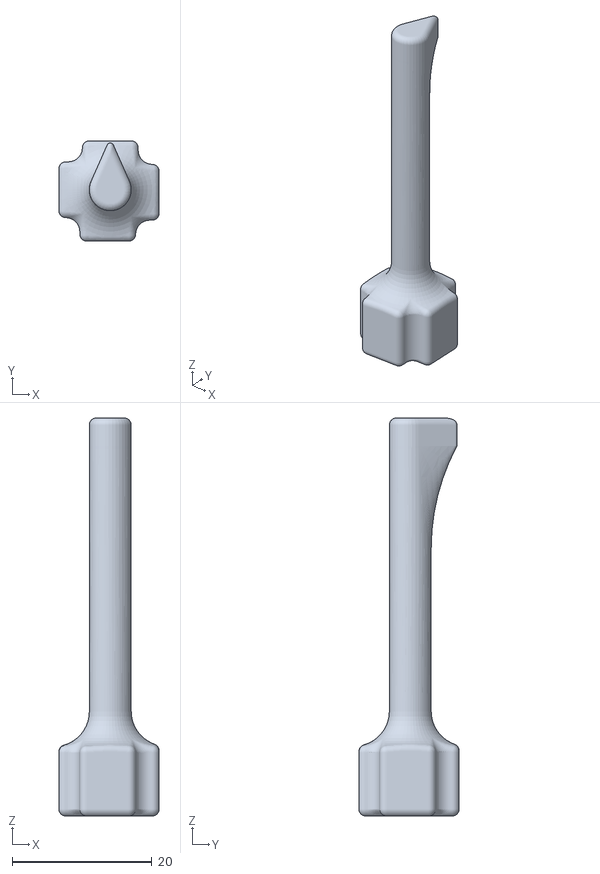
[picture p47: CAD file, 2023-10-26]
Impresion 3D STL/Agarre/Agarre_Traba.STL
14.4 x 14.4 x 57.0

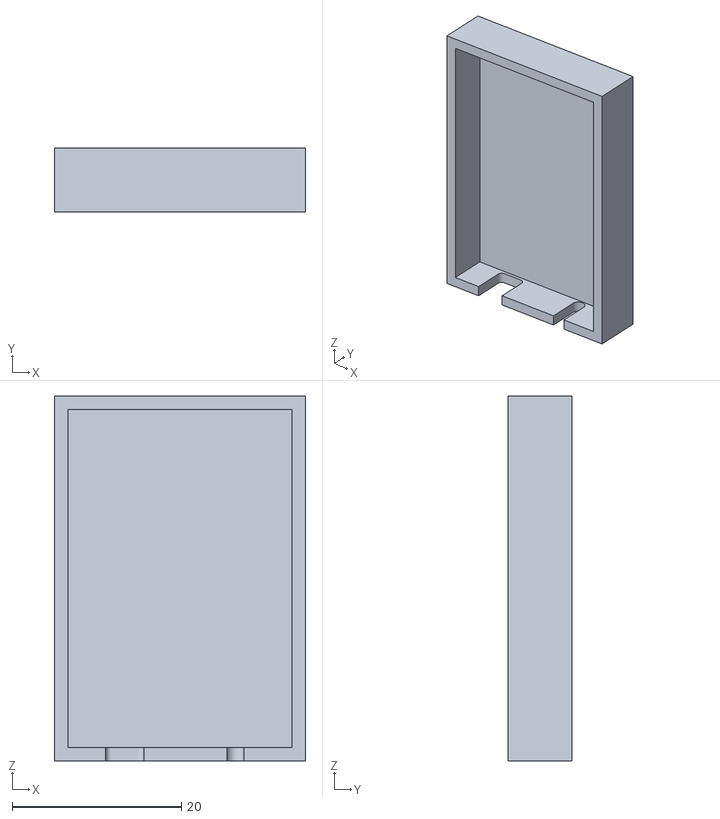
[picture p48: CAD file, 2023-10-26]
Impresion 3D STL/Pluviómetro/Pluv_Estanco B.STL
29.7 x 7.60 x 43.2

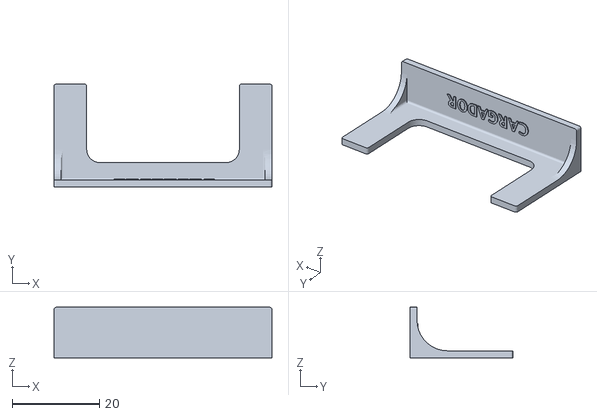
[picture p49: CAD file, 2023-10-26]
Impresion 3D STL/Telemetría/Tel_Holder Cargador.STL
50.0 x 23.6 x 11.6

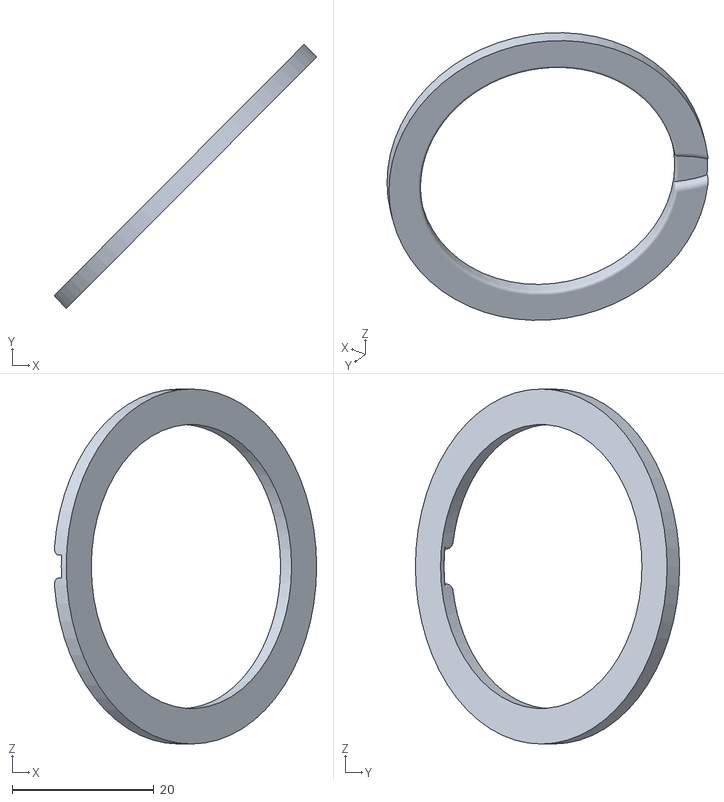
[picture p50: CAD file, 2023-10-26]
Impresion 3D STL/UV/UV_Tapa.STL
36.9 x 37.2 x 50.0

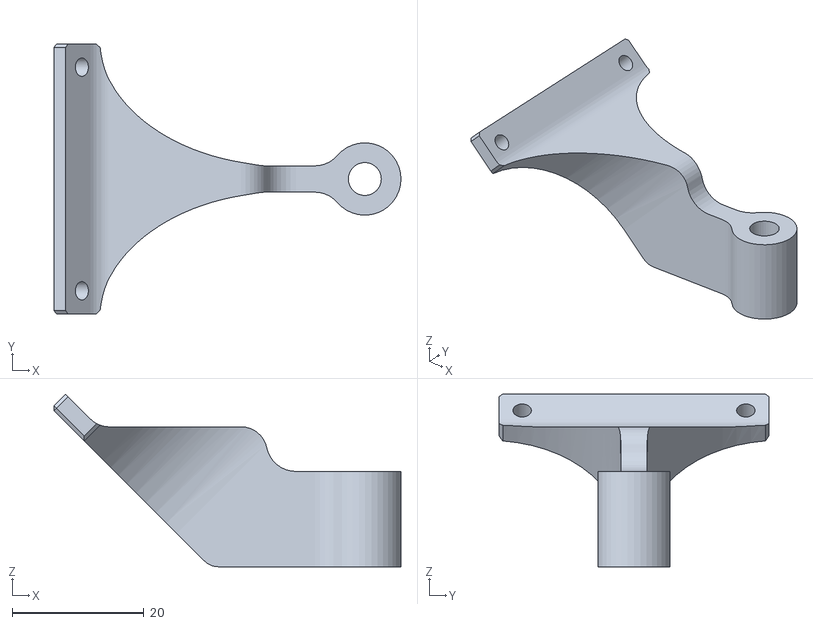
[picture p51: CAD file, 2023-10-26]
Impresion 3D STL/Pluviómetro/Pluv_Mensula.STL
52.8 x 41.0 x 26.2

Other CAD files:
Impresion 3D STL/Telemetría/Tel_Holder Step Up.STL
Impresion 3D STL/Pluviómetro/Pluv_Estanco A.STL
Impresion 3D STL/Telemetría/Tel_Tope.STL
Impresion 3D STL/Pluviómetro/Pluv_Aro.STL
Impresion 3D STL/Pluviómetro/Pluv_Tapa.STL
Impresion 3D STL/Telemetría/Tel_Pieza T.STL
Impresion 3D STL/Telemetría/Tel_Separador.STL
Impresion 3D STL/Telemetría/Tel_Tapa Inferior.STL

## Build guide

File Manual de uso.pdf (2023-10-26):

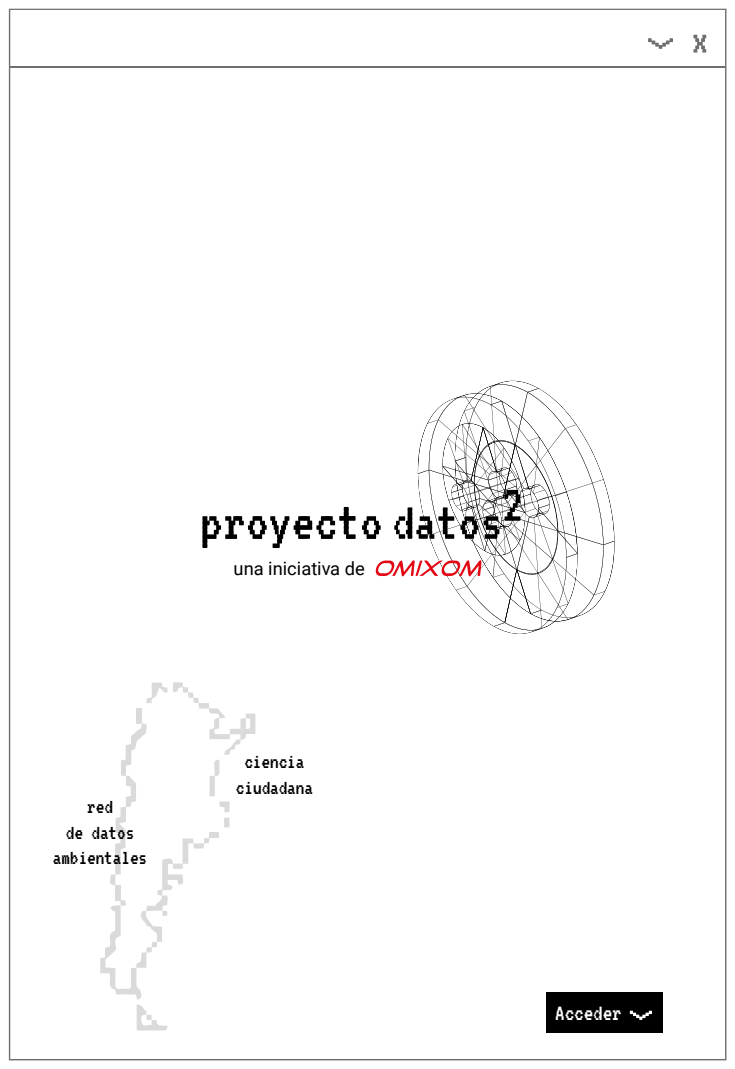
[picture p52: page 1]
Acceder; ciencia ciudadana; red de datos ambientales

una iniciativa de

### Rayos Ultravioleta

### Lluvia detectada

### Lluvia acumulada

### Temperatura ambiente

Permite conocer el inicio
y el final del fenómeno
de lluvia.

Mide la cantidad de agua
acumulada.
El valor se verá reflejado en milímetros de lluvia.

Registra la temperatura ambiente en grados centígrados. (C°)

Registra la humedad
relativa del ambiente y la representa en un
porcentaje. (%HR)

Mensura la intensidad
de los rayos UV
provenientes de la luz,
lo expresa en el rango
de 1 a 11.

### Humedad ambiente

### El proyecto Datos² desarrolló un dispositivo Open-Source con el fin de recolectar, almacenar y compartir datos ambientales de la mano de proyectos de ciencia ciudadana y de la comunidad en general. Buscamos que cada uno pueda apropiarse

del proyecto de la manera más conveniente,

### generando un impacto en el presente y futuro de

nuestra sociedad.

Para ello diseñamos la Estación Metereológica Automática (EMA) Datos² formada por diversos sensores, que podrán ser incorporados según las necesidades de las comunidades, y por una telemetría que se encargará de subir los datos a una plataforma web para su visualización. Desde aquí, toda la comunidad podrá utilizar los datos generados para

distintos proyectos o necesidades.

### una iniciativa de

## ¿Qué parametros mide?

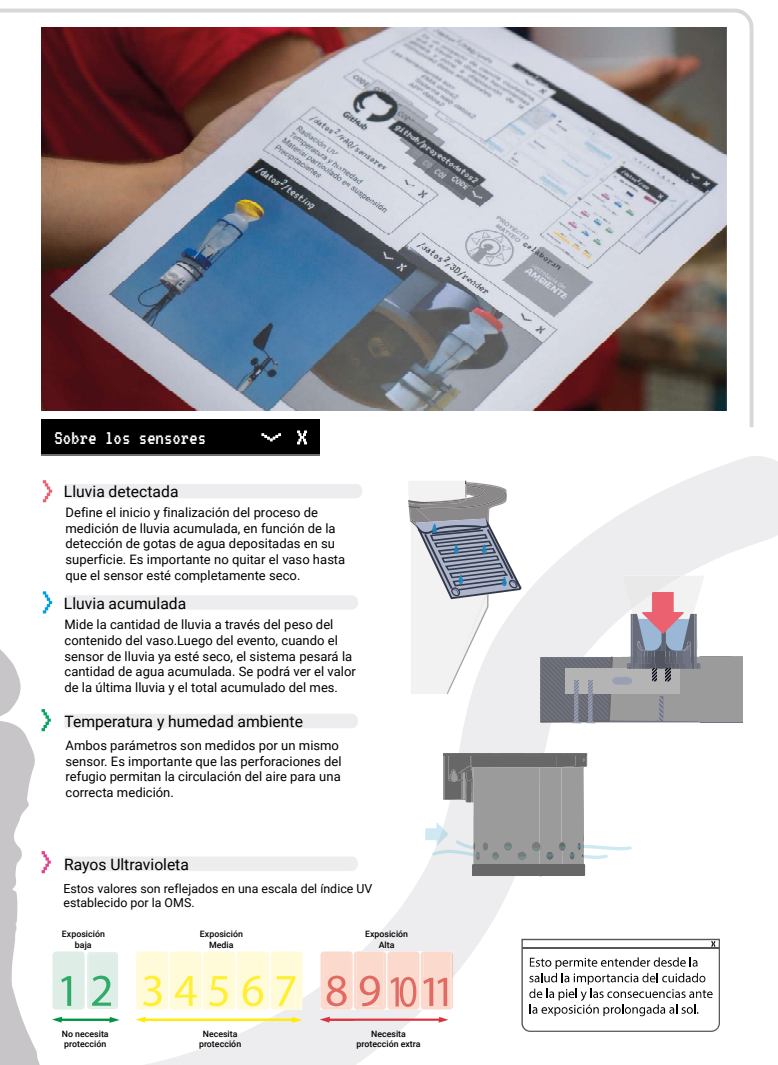
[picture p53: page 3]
No necesita protección; Exposición baja; Exposición Media; Exposición Alta; Necesita protección; Necesita protección extra

Sobre los sensores

Lluvia detectada
Define el inicio y finalización del proceso de
medición de lluvia acumulada, en función de la
detección de gotas de agua depositadas en su
superficie. Es importante no quitar el vaso hasta
que el sensor esté completamente seco.
Lluvia acumulada
Mide la cantidad de lluvia a través del peso del
contenido del vaso.Luego del evento, cuando el
sensor de lluvia ya esté seco, el sistema pesará la
cantidad de agua acumulada. Se podrá ver el valor
de la última lluvia y el total acumulado del mes.
Temperatura y humedad ambiente
Ambos parámetros son medidos por un mismo
sensor. Es importante que las perforaciones del
refugio permitan la circulación del aire para una
correcta medición.

Rayos Ultravioleta
Estos valores son reflejados en una escala del índice UV
establecido por la OMS.

## Cuidados/EMA

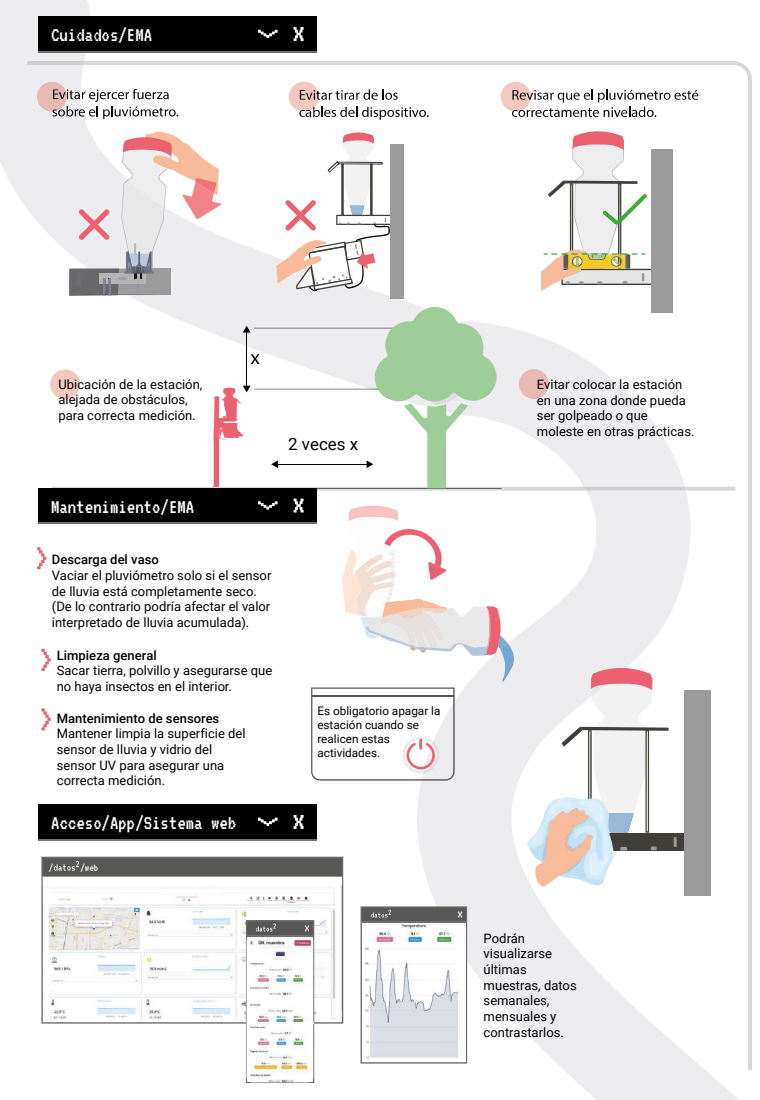
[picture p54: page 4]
Podrán visualizarse últimas muestras, datos semanales, mensuales y contrastarlos.; 2 veces x; Mantenimiento/EMA; /web

Ubicación de la estación,
alejada de obstáculos,
para correcta medición.

Evitar colocar la estación
en una zona donde pueda
ser golpeado o que
moleste en otras prácticas.

Descarga del vaso
Vaciar el pluviómetro solo si el sensor
de lluvia está completamente seco.
(De lo contrario podría afectar el valor
interpretado de lluvia acumulada).

Limpieza general
Sacar tierra, polvillo y asegurarse que
no haya insectos en el interior.

Es obligatorio apagar la
estación cuando se
realicen estas
actividades.

Mantenimiento de sensores
Mantener limpia la superficie del
sensor de lluvia y vidrio del
sensor UV para asegurar una
correcta medición.
Acceso/App/Sistema web

## /datos²/equipo

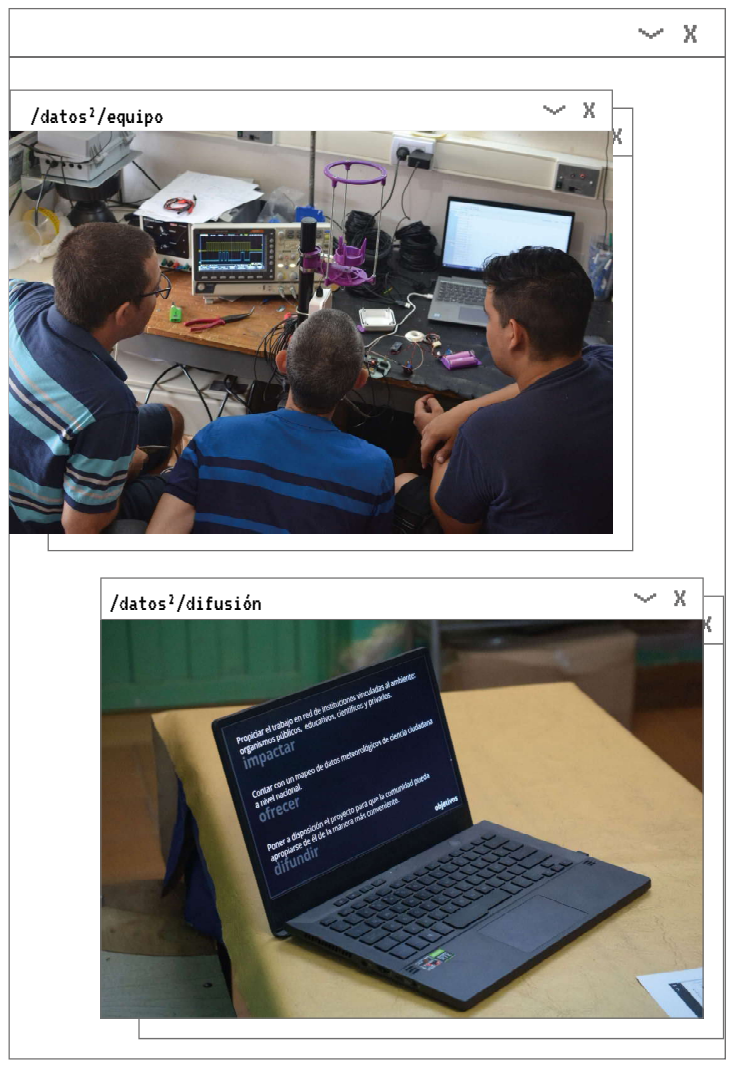
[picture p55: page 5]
/datos²/difusión

## /datos²/prototipado

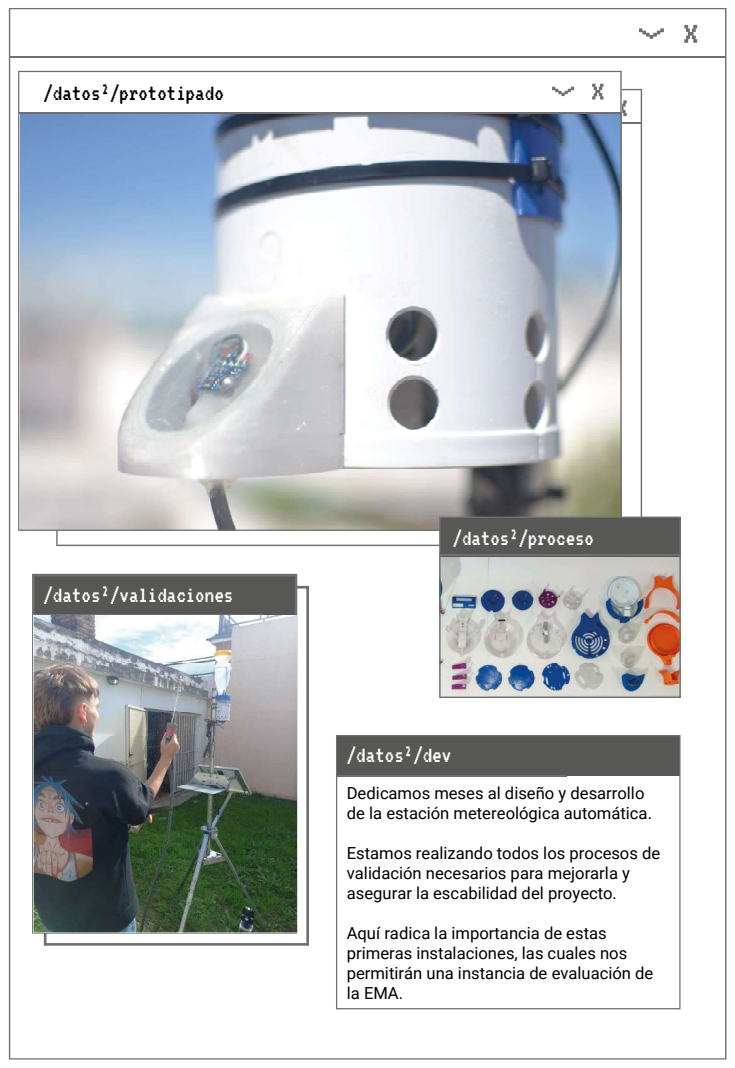
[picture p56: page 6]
/datos²/validaciones; /datos²/dev; /datos²/proceso

Dedicamos meses al diseño y desarrollo
de la estación metereológica automática.

Estamos realizando todos los procesos de
validación necesarios para mejorarla y
asegurar la escabilidad del proyecto.

Aquí radica la importancia de estas
primeras instalaciones, las cuales nos
permitirán una instancia de evaluación de
la EMA.

### Creemos que la acción por el clima

debe ser colectiva y ciudadana.

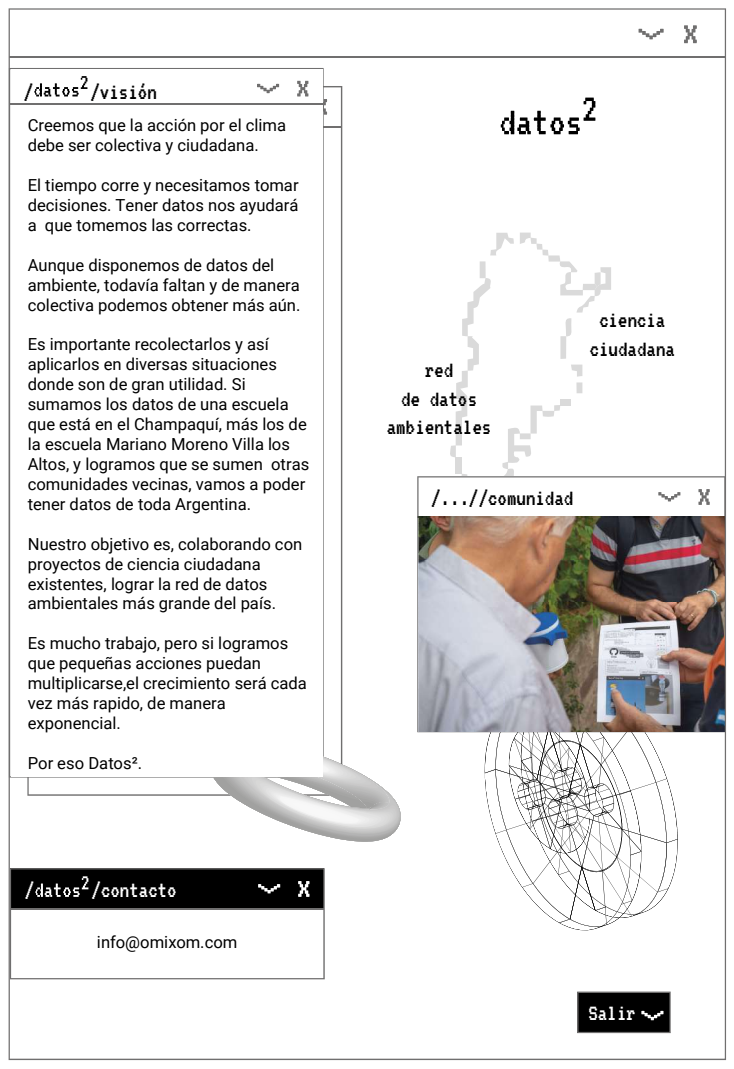
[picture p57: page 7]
/contacto; /...//comunidad; Salir; ciencia ciudadana; red de datos ambientales; /visión

El tiempo corre y necesitamos tomar
decisiones. Tener datos nos ayudará
a que tomemos las correctas.

Aunque disponemos de datos del
ambiente, todavía faltan y de manera
colectiva podemos obtener más aún.

Es importante recolectarlos y así
aplicarlos en diversas situaciones
donde son de gran utilidad. Si
sumamos los datos de una escuela
que está en el Champaquí, más los de
la escuela Mariano Moreno Villa los
Altos, y logramos que se sumen otras
comunidades vecinas, vamos a poder
tener datos de toda Argentina.

Nuestro objetivo es, colaborando con
proyectos de ciencia ciudadana
existentes, lograr la red de datos
ambientales más grande del país.

Es mucho trabajo, pero si logramos
que pequeñas acciones puedan
multiplicarse,el crecimiento será cada
vez más rapido, de manera
exponencial.

Por eso Datos².

info@omixom.com

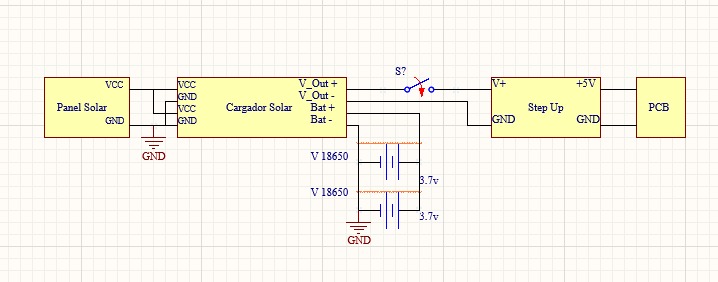
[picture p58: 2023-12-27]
Imagenes/Ensamble/Sistema de Autonomía/Conexionado Sistema de Autonomia.jpg

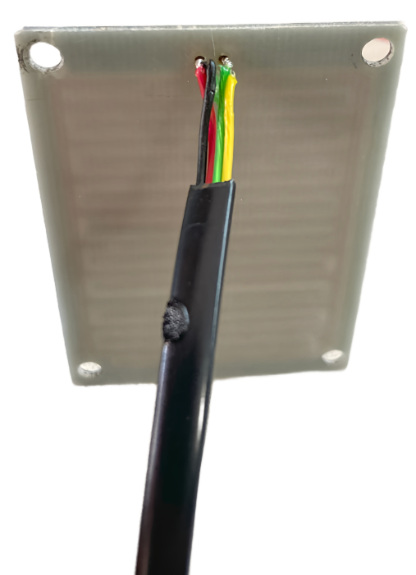
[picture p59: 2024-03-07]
Imagenes/Ensamble/Conjunto Pluviómetro/Conexion Sensor Raindrop.png

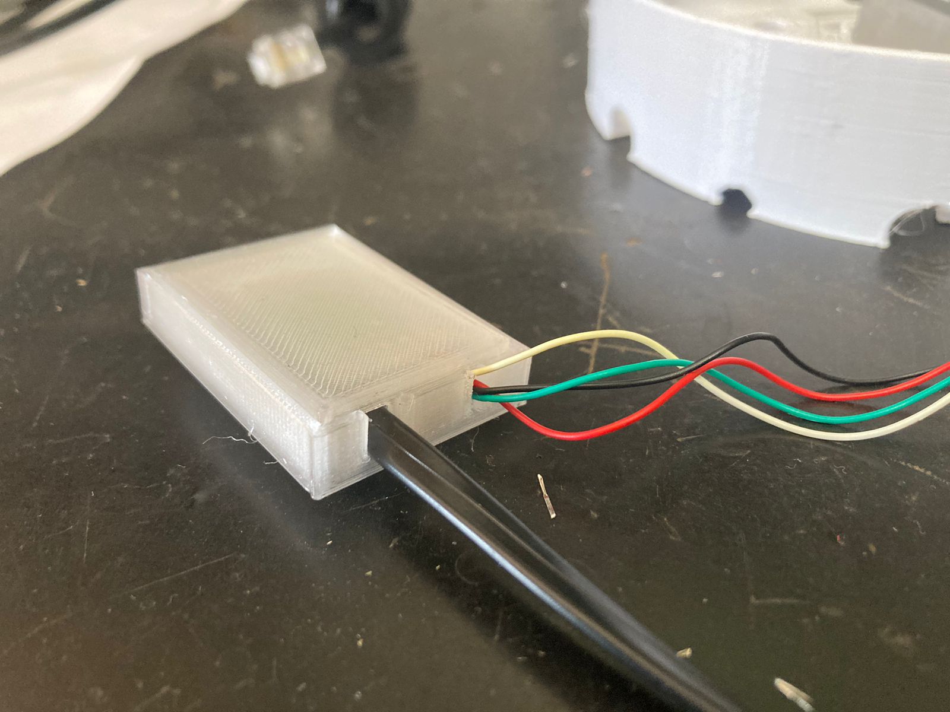
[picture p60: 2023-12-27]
Imagenes/Ensamble/Conjunto Pluviómetro/Colocación Driver Celda de Carga.jpg

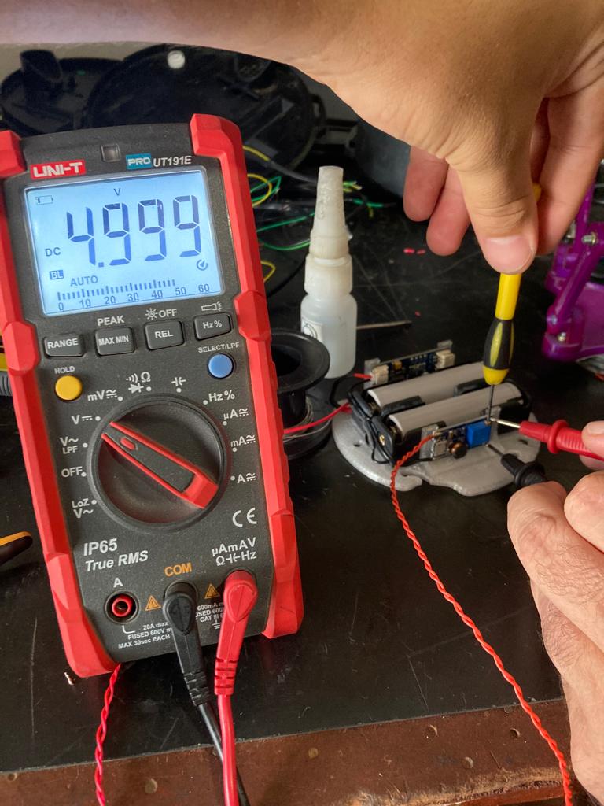
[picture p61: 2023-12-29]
Imagenes/Ensamble/Sistema de Autonomía/Regulacion de Step Up.jpg

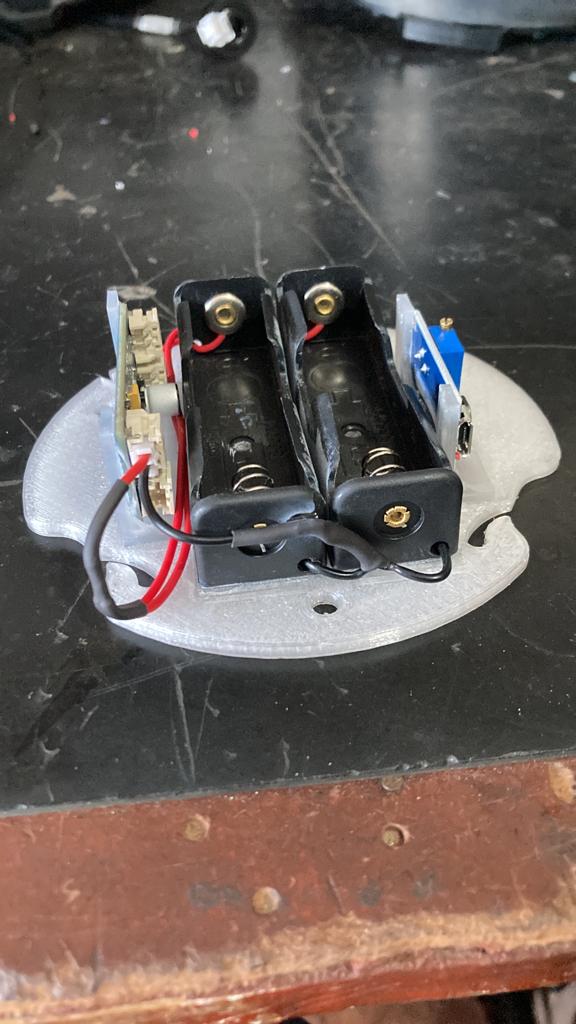
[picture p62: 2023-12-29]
Imagenes/Ensamble/Sistema de Autonomía/Empalme Negativos.jpg

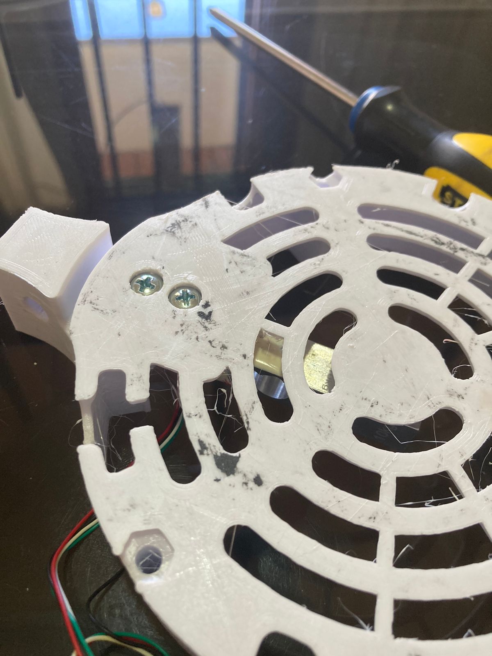
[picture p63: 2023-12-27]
Imagenes/Ensamble/Conjunto Pluviómetro/Tornillos Celda de Carga.jpg

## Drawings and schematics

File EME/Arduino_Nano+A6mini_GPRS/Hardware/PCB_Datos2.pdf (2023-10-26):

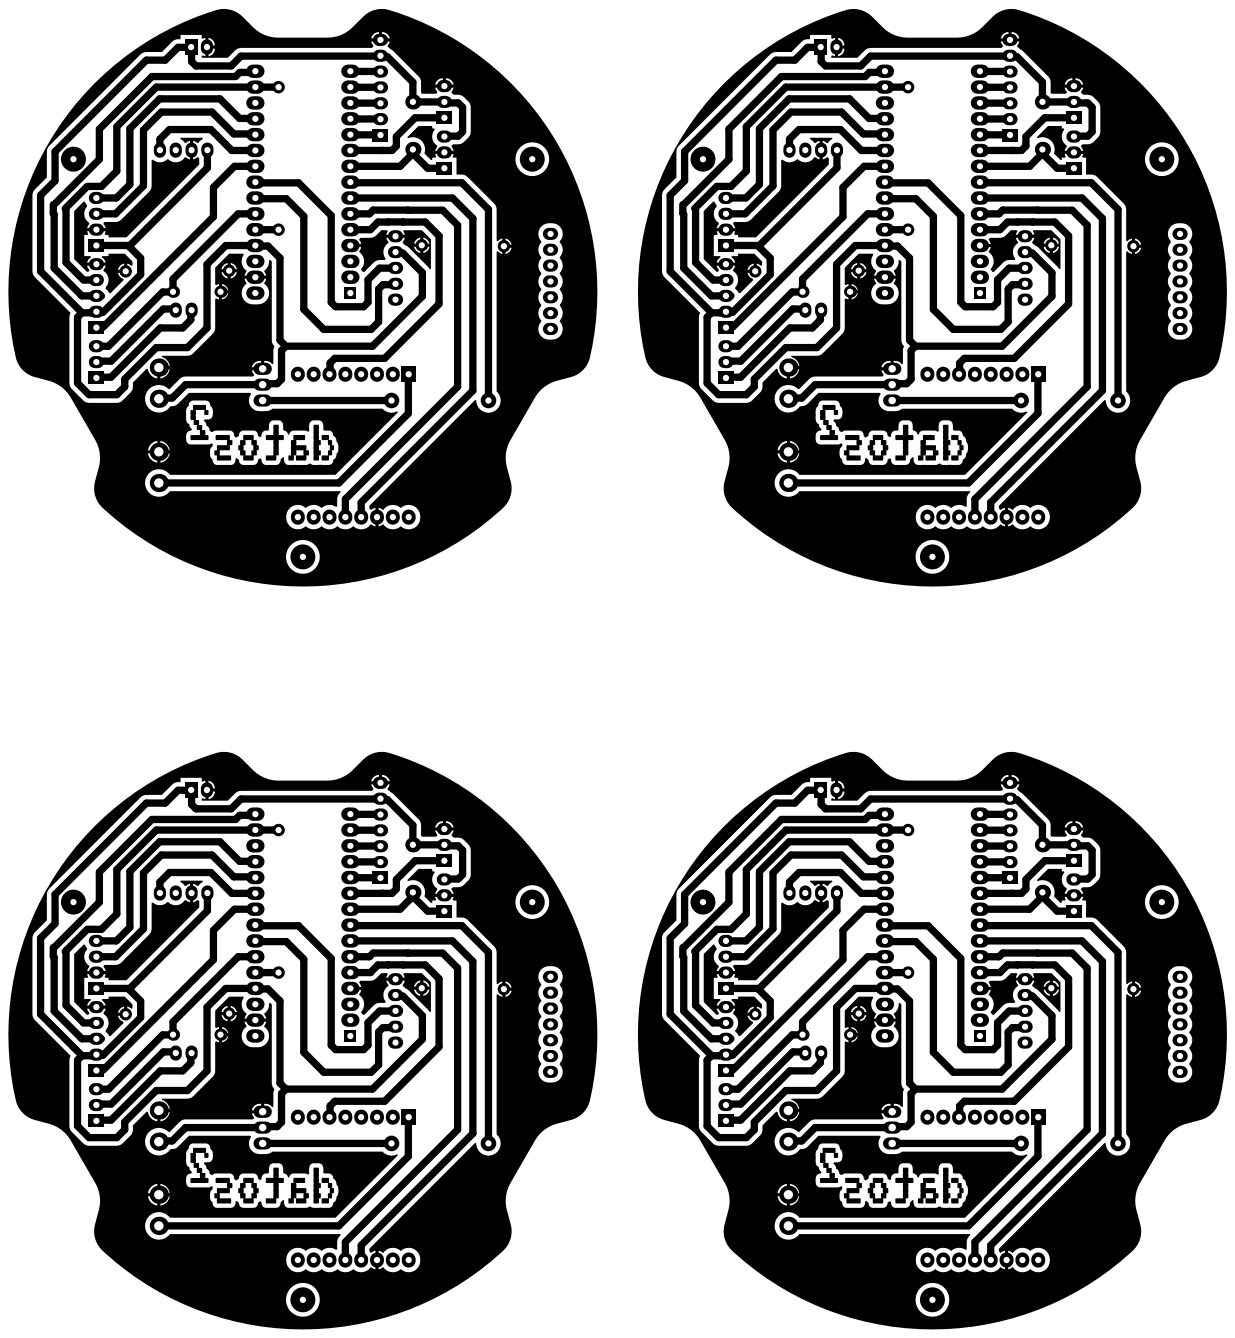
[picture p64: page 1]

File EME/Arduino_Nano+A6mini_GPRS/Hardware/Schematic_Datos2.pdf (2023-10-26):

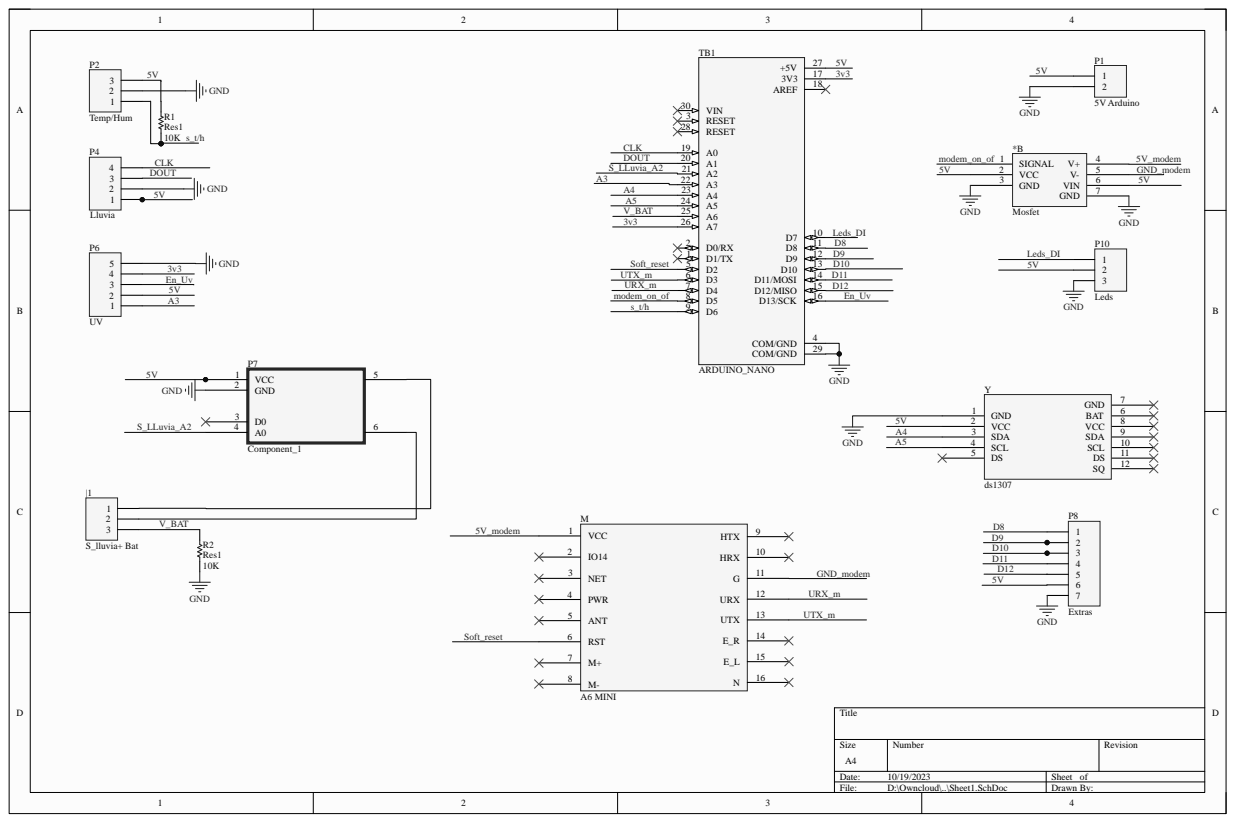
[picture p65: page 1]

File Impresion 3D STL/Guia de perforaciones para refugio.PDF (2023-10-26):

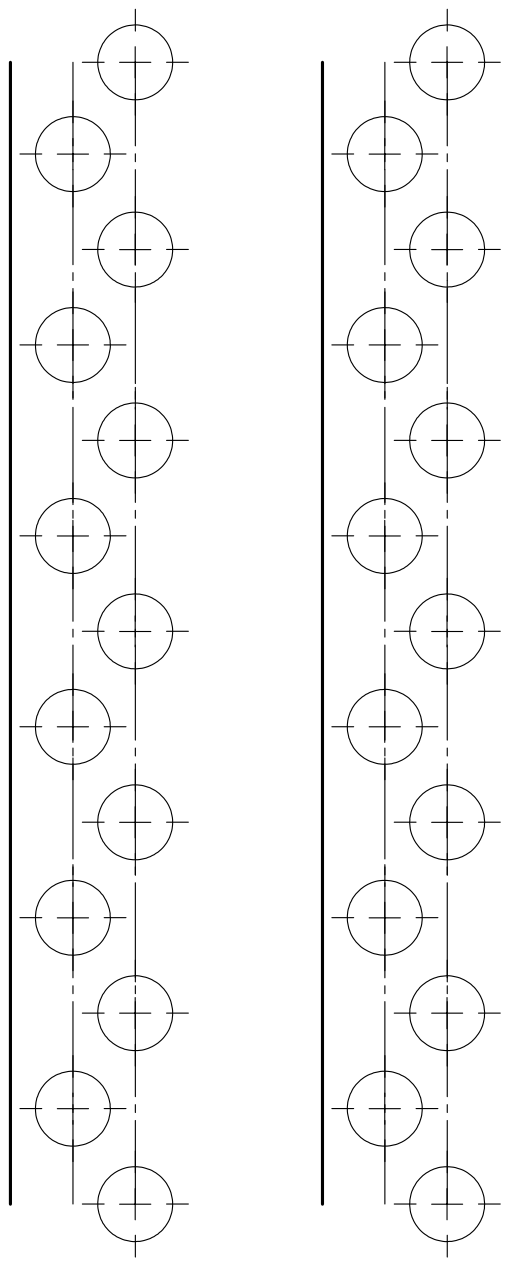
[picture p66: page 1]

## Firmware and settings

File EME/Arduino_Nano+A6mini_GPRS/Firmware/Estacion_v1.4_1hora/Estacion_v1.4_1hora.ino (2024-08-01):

#include <Wire.h>
#include "RTClib.h"          //RTC
#include "HX711.h"           //Driver Balanza
#include "DHT.h"             //T/H
#include "SoftwareSerial.h"  //puerto serie
#include <AT24CX.h>          // Memoria
#include "ModemDriver.h"     //Modem




//Comunicación modem
SoftwareSerial port(3, 4);
ModemDriver mdm(&port, 9600);




char trama[48] = "";
bool enviando_dato = false;
char dataRecibida[SERVER_RESP_SIZE] = "";

//serie
#define t_envio 1
#define t_registro 4
#define tipo 2
#define serie 5043


//rtc
RTC_DS1307 rtc;
DateTime HoraFecha;
#define memoria 227  //maxima cantidad de muestras
//lluvia
#define DOUT A1
#define CLK A0
#define s_lluvia_a2 A2
bool l = 0;
bool l1 = 0;
HX711 balanza;
int lluvia = 0;  // deberia ser long para poder alcanzar el rango de 10kg pero se lo utiliza hasta el rango de los 5 kg
int hora_anterior = 0;
bool forzado = false;
#define hora_forzado 12  //hora que se usa para saber cuando forzar una muestra. Se usa 9 am ya que de 9am a 9am es el periodo para tomar la lluvia diaria

//Tiempo
unsigned long t_actual;
unsigned long t_millis;
unsigned long t_millis_recept;

// On/off sensores
#define modem_on_of 5


//sensor T/H
#define DHTTYPE DHT22  // Sensor DHT22
#define DHTPIN 6       // Pin donde está conectado el sensor
DHT dht(DHTPIN, DHTTYPE);
float h = 0.0;
float t = 0.0;

//Sensor UV
#define ANALOGPIN A3
#define ENABLEPIN 13

float UV = 0;   //mide la radiación UV
float DUV = 0;  //indice UV

#define REF_3V3 A7  //3.3V power on the Arduino board
int uvLevel;
int refLevel;

//Memoria
AT24C32 EepromRTC;
//Variables que inciden en la secuencia del programa, el muestreo y guardado en memoria
int i = 0;
bool f = 0;
int recepcion = 0;  //se usa para la parte de envio de datos
//estructura de muestreo

byte hora = 0;
byte minuto = 0;
byte dia = 0;
byte mes = 0;
byte year = 0;
byte senal = 0;
byte bateria = 0;
byte estado_lluvia = 0;
byte humedad = 0;
byte d_u_v = 0;
int temperatura = 0;
int u_v = 0;
int pm25 = 0;
int lluvia_ps = 0;

//Bateria
#define V_BAT A6



// Conteo de muestras
byte pws = 0;
byte prs = 0;

//modem
int error = 0;             // cuenta los errores de un mal envio de muestras o que estan fuera de formato
bool dato = false;         // flag que indica si envie un dato o no y permite que se envie un nuevo dato
bool inicio = false;       // flag que indica si el modem esta prendido
int sin_respuesta = 0;     // cuenta los errores por no obtener respuesta
bool transmision = true;  //flag para permitir la transmision de datos
bool registro = false;     // flag para permitir el registro



void setup() {
  Serial.begin(115200);
  rtc.begin();  //Inicializamos el RTC
  balanza.begin(DOUT, CLK);
  balanza.set_scale(218);  // Establecemos la escala
  pinMode(s_lluvia_a2, INPUT);
  pinMode(modem_on_of, OUTPUT);
  pinMode(V_BAT, INPUT);
  digitalWrite(modem_on_of, HIGH);
  mdm.init();
  dht.begin();
  pinMode(ENABLEPIN, OUTPUT);
  digitalWrite(ENABLEPIN, HIGH);  /// habilitacion sensor UV
  pinMode(ANALOGPIN, INPUT);


  prs = EepromRTC.read(4090);
  pws = EepromRTC.read(4092);

 

  //rtc.adjust(DateTime(F(__DATE__), F(__TIME__)));
  // Serial.println(rtc.readnvram(0));

  Serial.print("iniciando");
}

void loop() {


  t_millis = millis();
  while (millis() <= t_millis + 2000) {
    delay(1);
  }



  HoraFecha = rtc.now();
  Serial.print(F("Version 1.6 "));
  Serial.print(F("hora "));
  Serial.print(HoraFecha.hour());
  Serial.print(F(" minuto "));
  Serial.print(HoraFecha.minute());
  Serial.print(F(" dia "));
  Serial.print(HoraFecha.day());
  Serial.print(F(" mes "));
  Serial.print(HoraFecha.month());
  Serial.print(F(" anio "));
  Serial.println(HoraFecha.year());
  Serial.print(F("prs "));
  Serial.println(prs);
  Serial.print(F("pws "));
  Serial.println(pws);



  // lluvia
  if ((analogRead(s_lluvia_a2) <= 870) && (l == 0)) {  //leo el estado del analogico y lo comparo con el nivel 800 del adc y consulto se vengo de un momento sin lluvia, si es menor es porque empezo a llover
    balanza.tare(20);                                  //El peso actual es considerado Tara.
    Serial.println("");
    Serial.println(F("-----------Tara-----------"));

    l = 1;
    l1 = 0;
    estado_lluvia = 1;

  } else if ((analogRead(s_lluvia_a2) >= 900) && (l == 1)) {
    l1 = 1;

    lluvia = lluvia + balanza.get_units(10);
    t_millis = millis();
    while (millis() <= t_millis + 1000) {
      delay(1);
    }
    Serial.println(F("------Listo para subir muestra------"));


    estado_lluvia = 0;
    l = 0;
  }
  ////////////


  // Muestreo
  while ((HoraFecha.minute() % 10) == 9) {  //en el minuto 59 empiezo el proceso sampling

    f = 1;
    t_actual = millis();  // pongo un valor en segundos al tiempo que uso de comparacion para el intervalo entre pedido de valores
    sampling();           //muestreo
    while (millis() < t_actual + 1000) {
      delay(1);
    }  //tiempo de espera para tomar una muestra

    HoraFecha = rtc.now();
  }
  //////////

  ////  Guardo muestras
  if (((HoraFecha.minute() % 10) == 0) && (f == 1)) {  // en el minuto 10 guardo las muestras para subir
    transmision = true;
    saving();
  }
  //////

  memset(dataRecibida, 0, sizeof(dataRecibida));  /// borro datos de entrada
  //Transmisión de datos
  if ((transmision == true) || (registro == true)) {
    Serial.println("Transmison de datos ---------------------------------------------------");
    if (registro == true) {
      send_data(1);
    } else if (prs != pws) {  // si son distintos inicio el proceso para subir a sistema
      send_data(0);
    } else {
      Serial.println(F("no hay muestras para subir "));
      digitalWrite(modem_on_of, LOW);  //apago el modem si no hay muestras que subir
      inicio = false;                  // indico que el modem esta apagado
      dato = false;                    // indico que se puede enviar un dato la proxima vez}
    }

  } else {  // si no estoy habilitado para transmitir
    Serial.println(F("no transmito"));
    digitalWrite(modem_on_of, LOW);  //apago el modem
    inicio = false;
    dato = false;
  }
  /////////////



  if ((dato == true) && (recepcion == 1)) {  // hay una respuesta del servidor y envie un dato
    recepcion = 0;

    if (strcmp(dataRecibida, "004F") == 0) {  // Si el servidor responde ok muevo un lugar prs
      dato = false;

      if (prs <= memoria) {
        prs++;
      } else {
        prs = 0;
      }
      error = 0;
      EepromRTC.write(4090, prs);


    } else if (strcmp(dataRecibida, "004565") == 0) {  // Si el servidor responde error  cuento 3 veces error y si no funciona avanzo prs de todas formas ya que hay un error en la muestra
      Serial.print(F("004565 "));
      dato = false;

      if (error == 2) {
        if (prs <= memoria) {
          prs++;
        } else {
          prs = 0;
        }
        error = 0;

        EepromRTC.write(4090, prs);
      } else {
        error++;
      }
    } else if ((dataRecibida[0] == '0') && (dataRecibida[1] == '2') && (dataRecibida[2] == '4') && (dataRecibida[3] == 'F')) {
      dato = false;
      registro = false;
      Serial.println("registro");
      char a[2] = "";
      char a2[2] = "";
      a[0] = dataRecibida[5];
      a2[0] = dataRecibida[7];
      int hora2 = (atoi(a) * 10) + atoi(a2);
      // Serial.print(F("hora "));
      // Serial.println(hora2);

      a[0] = dataRecibida[9];
      a2[0] = dataRecibida[11];
      int minutos2 = (atoi(a) * 10) + atoi(a2);
      // Serial.print(F("minuto "));
      // Serial.println(minutos2);

      a[0] = dataRecibida[13];
      a2[0] = dataRecibida[15];
      int dia2 = (atoi(a) * 10) + atoi(a2);
      // Serial.print(F("dia "));
      // Serial.println(dia2);

      a[0] = dataRecibida[17];
      a2[0] = dataRecibida[19];
      int mes2 = (atoi(a) * 10) + atoi(a2);
      // Serial.print(F("mes "));
      // Serial.println(mes2);

      a[0] = dataRecibida[21];
      a2[0] = dataRecibida[23];
      int anio2 = (atoi(a) * 10) + atoi(a2) + 2000;
      // Serial.print(F("anio "));
      // Serial.println(anio2);

      rtc.adjust(DateTime(anio2, mes2, dia2, hora2, minutos2, 0));  //2016,Junio,10,18 h,29 min,0 seg


    } else {
      memset(dataRecibida, 0, sizeof(dataRecibida));
    }


  } else if ((dato == true) && (recepcion == 0)) {  // si se envio un dato y no hay resuesta

  } else {
    memset(dataRecibida, 0, sizeof(dataRecibida));
  }

 // mdm.update();
}



void sampling() {
  Serial.println(F("sampling"));
  h = h + dht.readHumidity();                  //Leemos la Humedad y lo sumamos a la lectura anterior
  t = t + dht.readTemperature();               //Leemos la temperatura en grados Celsius y lo sumamos a la lectura anterior
  UV = UV + (analogRead(ANALOGPIN) * 0.0048);  //envio dato crudo del sensor UV
  i++;                                         //cuenta las veces que se pide valores a los sensores
}
void saving() {
  Serial.println(F("saving"));
  dia = HoraFecha.day();
  mes = HoraFecha.month();
  year = HoraFecha.year() % 1000;
  hora = HoraFecha.hour();
  minuto = HoraFecha.minute();
  senal = 31;
  bateria = (0.0048 * analogRead(V_BAT)) * 10;
  temperatura = (((t / i) + 40) * 100);  //sumo 40 para enviar siempre temperaturas positivas casteo t a int para que ocupe menos espacio en la memoria
  humedad = (h / i);                     //casteo h a int para que ocupe menos espacio en la memoria

 
  u_v = ((UV / i) * 100);  //casteo uv a int para que ocupe menos espacio en la memoria mando el dato crudo del analogico

  uvLevel = analogRead(ANALOGPIN);
  refLevel = analogRead(REF_3V3);

  float outputVoltage = 3.3 / refLevel * uvLevel;
  d_u_v = mapfloat(outputVoltage, 0.96, 2.8, 0.0, 15.0);  //Convert the voltage to a UV intensity level

  pm25 = 0;

  if (l1 == 1) {  //cuando se cumple un ciclo de mojado a seco, sube la lluvia acumulada desde que se realizo la tara.
                  // Serial.print("lluvia en samplig ");
    lluvia_ps = lluvia;
    if (lluvia_ps < 0) {
      lluvia_ps = 0;
    }
    l1 = 0;
    lluvia = 0;
  } else {
    if ((HoraFecha.hour() == hora_forzado) && (HoraFecha.minute() == 0)) {  //cuando son las 9am toma una muestra y sube el valor de lluvia sin importar si aun lleve o no. Luego si esta lloviendo hace una tara y sigue tomando muestras normalmente
      registro = true;
      //Serial.println(F("Lluvia forzado---------------"));

      lluvia_ps = lluvia + balanza.get_units(10);
      t_millis = millis();
      while (millis() <= t_millis + 1000) {
        delay(1);
      }

      if (lluvia_ps < 0) {
        lluvia_ps = 0;
      }
      balanza.tare(20);  //El peso actual es considerado Tara.
      Serial.println("");
      Serial.println(F("-----------Tara forzada-----------"));

      lluvia = 0;
    } else {
      lluvia_ps = 0;
    }
  }


  writing();

  f = 0;
  i = 0;   //vuelvo a 0 el conteo de mustras en samplig
  h = 0;   //vuelvo a 0 la humedad
  UV = 0;  //vuelvo a 0 uv
  DUV = 0;
  t = 0;  //vuelvo a 0 la temperatura
}

void writing() {
 

  int pos_mem = pws * 18;  // int pos_mem = (pws * 20) + 1;
  EepromRTC.write(pos_mem, hora);
  EepromRTC.write(pos_mem + 1, minuto);
  EepromRTC.write(pos_mem + 2, dia);
  EepromRTC.write(pos_mem + 3, mes);
  EepromRTC.write(pos_mem + 4, year);
  EepromRTC.write(pos_mem + 5, senal);
  EepromRTC.write(pos_mem + 6, bateria);
  EepromRTC.write(pos_mem + 7, estado_lluvia);
  EepromRTC.writeInt(pos_mem + 8, temperatura);
  EepromRTC.write(pos_mem + 10, humedad);
  EepromRTC.writeInt(pos_mem + 11, u_v);
  EepromRTC.write(pos_mem + 13, d_u_v);
  EepromRTC.writeInt(pos_mem + 14, lluvia_ps);
  EepromRTC.writeInt(pos_mem + 16, pm25);

  lluvia_ps = 0;

  if (pws <= memoria) {
    pws++;
  } else {
    pws = 0;
  }

  //rtc.writenvram(0, pws);
  EepromRTC.write(4092, pws);
}

void read_build() {  // leo la memoria segun prs, armo la cadena para enviar al servidor y envio
  Serial.println(F("read_build"));
  memset(trama, 0, sizeof(trama));
  char aux[5] = "";
  sprintf(aux, "%02X", t_envio);  //codigo de trama para registrarse
  strcat(trama, aux);
  sprintf(aux, "%02X", tipo);  //codigo de tipo de equipo
  strcat(trama, aux);
  sprintf(aux, "%04X", serie);  //numero de serie del equipo
  strcat(trama, aux);

  int pos_mem = prs * 18;

  sprintf(aux, "%02X", EepromRTC.read(pos_mem));  //hora
  strcat(trama, aux);

  sprintf(aux, "%02X", EepromRTC.read(pos_mem + 1));  //minuto
  strcat(trama, aux);

  sprintf(aux, "%02X", EepromRTC.read(pos_mem + 2));  //, dia
  strcat(trama, aux);

  sprintf(aux, "%02X", EepromRTC.read(pos_mem + 3));  //, mes
  strcat(trama, aux);

  sprintf(aux, "%02X", EepromRTC.read(pos_mem + 4));  //, year
  strcat(trama, aux);

  sprintf(aux, "%02X", EepromRTC.read(pos_mem + 5));  //, senal
  strcat(trama, aux);

  sprintf(aux, "%02X", EepromRTC.read(pos_mem + 6));  //, bateria
  strcat(trama, aux);

  sprintf(aux, "%02X", EepromRTC.read(pos_mem + 7));  //, estado_lluvia
  strcat(trama, aux);

  sprintf(aux, "%04X", EepromRTC.readInt(pos_mem + 8));  //, temperatura
  strcat(trama, aux);


  sprintf(aux, "%02X", EepromRTC.read(pos_mem + 10));  //, humedad
  strcat(trama, aux);

  sprintf(aux, "%04X", EepromRTC.readInt(pos_mem + 11));  //, UV
  strcat(trama, aux);

  sprintf(aux, "%02X", EepromRTC.read(pos_mem + 13));  //, DUV
  strcat(trama, aux);

  sprintf(aux, "%04X", EepromRTC.readInt(pos_mem + 14));  //, lluvia
  strcat(trama, aux);

  sprintf(aux, "%04X", EepromRTC.readInt(pos_mem + 16));  //, pm25

  strcat(trama, aux);


  strcat(trama, "0F");


  // Serial.print("Trama: ");
  // Serial.println(trama);
}
void registrando() {
  memset(trama, 0, sizeof(trama));
  char aux[5] = "";
  sprintf(aux, "%02X", t_registro);  //codigo de trama para registrarse
  strcat(trama, aux);
  sprintf(aux, "%02X", tipo);  //codigo de tipo decequipo
  strcat(trama, aux);
  sprintf(aux, "%04X", serie);  //numero de serie del equipo
  strcat(trama, aux);
}
void send_data(bool n) {

  if (inicio == false) {  // verifico si el modem esta prendido o esta apagado
    digitalWrite(modem_on_of, HIGH);//prendo el modem
    mdm.init();
    t_millis = millis();
    while (millis() <= t_millis + 20000) {
      delay(1);
    }
    mdm.update();
    inicio = true;
  }


  if (mdm.uploaded() && !mdm.available() && dato == false) {  //modem habilitado para subir un dato, no hay respuesta del servidor y no se esta enviando un dato anterior
    Serial.println(F("enviando "));
    dato = true;
    if (n == 1) {
      registrando();  //forma la cadena trama de registro
    } else {
      read_build();  //forma la cadena trama de envio de datos
    }

    mdm.upload(trama);

    memset(trama, 0, sizeof(trama));

    t_millis_recept = millis();

    while (recepcion == 0) {
      if (mdm.available()) {  //espero una respuesta del servidor
        mdm.getResponse(dataRecibida);
        Serial.print(F("RESPUESTA DEL SERVIDOR: "));
        Serial.println(dataRecibida);
        recepcion = 1;
      } else if (millis() >= t_millis_recept + 240000) {  //espero 2 minutos y si no hay respuesta intento eviar de nuevo la muestra
        inicio = false;                                   // indico que el modem esta apagado
        Serial.print(F("no hubo respuesta"));
        dato = false;
        transmision = false;
        return;
      }
      mdm.update();
      delay(100);
    }
  }
}
float mapfloat(float x, float in_min, float in_max, float out_min, float out_max) {
  return (x - in_min) * (out_max - out_min) / (in_max - in_min) + out_min;
}

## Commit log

2023-10-26 Initila commit
    [Aro totalizador sensor lluvia.STL, Base sensor uv.STL, Cuerpo sensor uv.STL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]
2023-10-26 Mover pdfs a la carpeta Imprension 3D
2023-11-07 Modificación de prueba en readme
2023-11-21 Update README.md
    Se agrega imagen de sehma
2023-11-21 Update README.md
    Borre la foto, para crear una branch donde vea como poner la foto
2023-11-21 Alineación de la foto SEHMA con el tecto
2023-11-21 Update README.md
    Se terminó la tabla de componentes electronicos
2023-11-22 Update README.md
    Se agregó el parrafo de la estructura
2023-11-24 Update README.md
    Se agregó materiales de ferreteria
2023-11-24 Agrego Fotos para Ensamblaje
2023-11-27 "Agrego Ensamblaje PCB"
2023-11-27 Edit Ensamblaje PCB
2023-12-12 Readme Update
    [Aro totalizador sensor lluvia.STL, Base sensor uv.STL, Cuerpo sensor uv.STL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]
2024-01-04 arbol de carpetas para los distintos tipos de hardware y firmware
2024-02-01 Change Images to match new 3d prints
2024-02-07 Update UV sensor steps to be more explicit
2024-02-07 Update Images for the uv sensor to match new 3D printings
2024-02-07 Readjust uv sensor picture to a smaller size
2024-02-19 Add raindrop sensor explanation
2024-02-20 Add a final view for the UV sensor
2024-02-20 Added explanations for RTC and Antenna build
2024-02-22 Change Telemetrias STL files and references
    [Tel_Holder Cargador.STL, Tel_Holder Step Up.STL, Tel_Pieza T.STL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]
2024-02-22 Change UV STL files and references
    [UV_Base.STL, UV_Cuerpo.STL, UV_Tapa.STL]
2024-02-22 Change Pluviometro STL file names and references
    [Pluv_Aro.STL, Pluv_Estanco A.STL, Pluv_Estanco B.STL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]
2024-02-22 Change Agarre STL file names
    [Agarre_Fijacion.STL, Agarre_Mariposa.STL, Agarre_Traba.STL]
2024-02-22 Change printing table lists
2024-02-22 Revert accidental pushes
    [Tel_Holder Cargador.STL, Tel_Holder Step Up.STL, Tel_Pieza T.STL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]
2024-03-07 Add step for UV sensor placing
2024-03-07 Translate miscellaneous and print tables
2024-03-07 Translate first parragraph of pcb
2024-03-07 Translate soldering step
2024-03-07 Add translation to soldering steo
2024-03-07 Translate UV Sensor step
2024-03-25 Add checklist
    [Checklist Datos2.xlsx]
2024-04-19 Resolve link to pcb pdf
2024-04-19 Add length of a screw in list
2024-05-02 Add files via upload
    Libreria para el uso del modem A6 mini
2024-05-03 Enhace Checklist
    [Checklist Datos2.xlsx]
2024-05-03 Correct size for better print
    [Checklist Datos2.xlsx]
2024-05-03 Add PCB row
    [Checklist Datos2.xlsx]
2024-05-03 Add dupont terminal row
    [Checklist Datos2.xlsx]
2024-05-03 Add Antena row
    [Checklist Datos2.xlsx]
2024-06-11 Elimina el listado de materiales en cada apartado
2024-06-11 Explica mas claro la centidad de molex
2024-06-11 Agrega hipervinculos a tablas de impresion
2024-06-11 Mejora formateo de paso UV
2024-06-11 Mejora la explicacion del armado cable antena
2024-06-11 Agrega el largo del cable trenzado
2024-06-11 Mejora explicacion de conexion sistema autonomia
2024-06-11 Corrige error en hipervinculo de impresiones
2024-06-11 Mejora explicacion de cables celda de carga
2024-06-11 Mejora explicacion sensor UV
2024-06-11 Corrige fuente de foto dependiente de modo oscuro
2024-06-24 guardo los cambios que voy haciendo
2024-06-25 termine componentes y materiales
2024-06-26 fin de 26/06/24
2024-06-27 Cambio de nombre al manual
2024-07-17 corrección de errores ortográficos
2024-07-29 Agrega link para cambiar de idioma
2024-07-29 Traduccion de la introduccion
2024-07-29 Traduce cuadros que listan materiales
2024-07-29 Traduce armado de PCB
2024-07-29 Traduce sistema de autonomia
2024-07-29 Traduce sensor UV
2024-07-29 Traduce integracion de sistemas electricos
2024-07-31 Se comenta la linea del numero de serie para que no se cometa el error de tener dos estaciones con el mismo numero de serie
    [Estacion_v1.4_1hora.ino]
2024-07-31 Cambia nombre de carpeta SEHMA a EME
2024-07-31 Cambia hipervinvulo del Armado de PCB
2024-07-31 Cambia hipervinculo de Datos2 y EME
2024-07-31 Cambia hipervinculo de Sistema de Autonomia
2024-07-31 Cambia hipervinculo de UV
2024-07-31 Cambia hipervinculos de Pluviometro
2024-07-31 Cambia hipervinculo de integracion de sis elec
2024-07-31 Cmabia hipervinculo de Integracion total
2024-08-01 Actualiza Checklist de materiales
    [Checklist Datos2.xlsx, Checklist componentes y materiales.xlsx]
